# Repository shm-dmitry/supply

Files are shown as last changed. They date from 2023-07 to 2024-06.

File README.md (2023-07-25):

Supply for my purposes

Yes, I know about china and ali.

But it was intresting to create it manually.

Input: AC 180..240V

Outputs:
1. DC 0..50V up to 10A (banana jack). Support CV and CC modes.
2. DC 5V up to 15A (banana jack & 2.54 pin pannel)
3. DC 3.3V up to 1A
4. one PWM channel 5V & 3.3V up to 1A each (configured from UI)
5. one USB port with QC2.0 chip (up to 18W)
6. two USB ports with 5V/1.5A output
7. One Li-Ion charger with 1A output current

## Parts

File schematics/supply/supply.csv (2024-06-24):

Source: | /opt/work-iot/supply/schematics/supply/supply.kicad_sch
Date: | Вт 26 дек 2023 18:33:18
Tool: | Eeschema 7.0.9-7.0.9~ubuntu22.04.1
Generator: | /usr/share/kicad/plugins/bom_csv_grouped_by_value_with_fp.py
Component Count: | 283
Ref | Qnty | Value | Cmp name | Footprint | Description | Vendor | DNP
C1, C7, C20, C27, C39, C50, C52 | 7 | 100 nF | C | Capacitor_SMD:C_0603_1608Metric | Unpolarized capacitor
C2, C17, C19, C22, C23, C25 | 6 | 22 uF | C | Capacitor_SMD:C_1210_3225Metric | Unpolarized capacitor
C3, C6, C64, C65, C66, C67 | 6 | 10 uF | C | Capacitor_SMD:C_0603_1608Metric | Unpolarized capacitor
C4, C42, C61, C62 | 4 | 10 nF | C | Capacitor_SMD:C_0603_1608Metric | Unpolarized capacitor
C5, C51 | 2 | 2 nF | C | Capacitor_SMD:C_0603_1608Metric | Unpolarized capacitor
C8, C10, C11, C26, C38, C45, C48, C49, C53, C54, C63 | 11 | 1 uF | C | Capacitor_SMD:C_0603_1608Metric | Unpolarized capacitor
C9 | 1 | 220 uF@35V | C_Polarized | Capacitor_THT:CP_Radial_D8.0mm_P3.50mm | Polarized capacitor
C12, C13 | 2 | К73-17 0.15 uF@400V | C | Capacitor_THT:C_Rect_L16.5mm_W7.3mm_P15.00mm_MKT | Unpolarized capacitor
C14, C15 | 2 | К73-17 0.022 uF@630V | C | Capacitor_THT:C_Rect_L13.0mm_W6.0mm_P10.00mm_FKS3_FKP3_MKS4 | Unpolarized capacitor
C16, C21, C24 | 3 | 1000 uF@16V | C_Polarized | Capacitor_THT:CP_Radial_D10.0mm_P5.00mm | Polarized capacitor
C18 | 1 | 2200 uF@35V | C_Polarized | Capacitor_THT:CP_Radial_D16.0mm_P7.50mm | Polarized capacitor
C28, C29, C30, C31, C34, C35, C36, C37, C43, C44, C46, C47 | 12 | 220 nF | C | Capacitor_SMD:C_0603_1608Metric | Unpolarized capacitor
C32, C33 | 2 | 15 pF | C | Capacitor_SMD:C_0603_1608Metric | Unpolarized capacitor
C40, C41, C68 | 3 | 0.1 uF | C | Capacitor_SMD:C_0603_1608Metric | Unpolarized capacitor
C55, C57 | 2 | К73-17 1 uF@400V | C | Capacitor_THT:C_Rect_L24.0mm_W12.8mm_P22.50mm_MKT | Unpolarized capacitor
C56, C58 | 2 | К73-17 0.33 uF@630V | C | Capacitor_THT:C_Rect_L24.0mm_W12.2mm_P22.50mm_MKT | Unpolarized capacitor
C59, C60 | 2 | 2200 uF@63V | C_Polarized | Capacitor_THT:CP_Radial_D18.0mm_P7.50mm | Polarized capacitor
C69 | 1 | 22 pF | C | Capacitor_SMD:C_0603_1608Metric | Unpolarized capacitor
CLR1, CLR4 | 2 | HS 216-30@30х51х25.5mm | COOLER | Library:HS 216-30
CLR2, CLR3 | 2 | HS 239-20 | COOLER | Library:HS-239-20
D1 | 1 | SR540 | D | Diode_THT:D_DO-201AD_P3.81mm_Vertical_AnodeUp | Diode
D2, D6, D9 | 3 | red/green, common cathode, F3 | LED_Dual_AKA | LED_THT:LED_D5.0mm-3 | Dual LED, common cathode on pin 2
D3, D21 | 2 | STTH1R06A | D | Diode_SMD:D_SMA | Diode
D4 | 1 | SMAJ26A | SMAJ26A | Diode_SMD:D_SMA | 400W unidirectional Transient Voltage Suppressor, 26.0Vr, SMA(DO-214AC)
D5, D7, D23, D24, D25, D26 | 6 | SMAJ5.0CA-TR | ESD9B3.3ST5G | Diode_SMD:D_SMA | ESD protection diode, 3.3Vrwm, SOD-923
D8, D22 | 2 | STTH3003CW | D_Dual_CommonCathode_AKA | Package_TO_SOT_THT:TO-247-3_Vertical | Dual diode, common cathode on pin 2
D10, D11 | 2 | SMCJ5.0A | Z3SMCxxx | Diode_SMD:D_SMC | 3000mW Zener Diode, SMC(DO-214AB)
D12 | 1 | L-2060YD | LED | LED_THT:LED_D1.8mm_W3.3mm_H2.4mm | Light emitting diode
D13 | 1 | GNL-3012ED | LED | Connector_JST:JST_XH_B2B-XH-A_1x02_P2.50mm_Vertical | Light emitting diode
D14 | 1 | GNL-3012GD | LED | Connector_JST:JST_XH_B2B-XH-A_1x02_P2.50mm_Vertical | Light emitting diode
D15, D16, D17, D18, D19, D20 | 6 | BAV21WS | D | Diode_SMD:D_SOD-323F | Diode
D27 | 1 | yellow | LED |  | Light emitting diode |  | DNP
D28 | 1 | green | LED |  | Light emitting diode |  | DNP
F1 | 1 | 5A | Fuse | Connector_Wire:SolderWire-0.75sqmm_1x02_P4.8mm_D1.25mm_OD2.3mm | Fuse
F2, F3, F5, F6 | 4 | 3A | Fuse | Connector_Wire:SolderWire-0.75sqmm_1x02_P4.8mm_D1.25mm_OD2.3mm | Fuse
F4 | 1 | 1808, 2A | Fuse | Library:FuseHolder1808 | Fuse
F7, F8 | 2 | 15A | Fuse |  | Fuse |  | DNP
J1 | 1 | Conn_01x02_Pin | Conn_01x02_Pin | Connector_Wire:SolderWire-1.5sqmm_1x02_P6mm_D1.7mm_OD3mm | Generic connector, single row, 01x02, script generated
J2, J3, J5, J6 | 4 | RFShield_OnePiece | RFShield_OnePiece | Library:EMI_SHIELD_1P_2H | One-piece EMI RF shielding cabinet
J4 | 1 | Conn_01x01_Pin | Conn_01x01_Pin | Connector_Wire:SolderWire-1.5sqmm_1x01_D1.7mm_OD3.9mm | Generic connector, single row, 01x01, script generated
J7, J8, J9 | 3 | USB_A | USB_A | Library:USB_A | USB Type A connector
J10, J11, J12, J13 | 4 | Conn_01x04_Pin | Conn_01x04_Pin | Connector_JST:JST_XH_B4B-XH-A_1x04_P2.50mm_Vertical | Generic connector, single row, 01x04, script generated
J14, J15 | 2 | USBASP | Conn_02x05_Odd_Even | Library:DC3-2x05_p2.54 | Generic connector, double row, 02x05, odd/even pin numbering scheme (row 1 odd numbers, row 2 even numbers), script generated (kicad-library-utils/schlib/autogen/connector/)
J16 | 1 | JST XH B3B | Conn_01x03_Socket | Connector_JST:JST_XH_B3B-XH-A_1x03_P2.50mm_Vertical | Generic connector, single row, 01x03, script generated
J17 | 1 | Conn_01x06_Pin | Conn_01x06_Pin | Connector_JST:JST_XH_B6B-XH-A_1x06_P2.50mm_Vertical | Generic connector, single row, 01x06, script generated
J18 | 1 | Conn_01x03_Pin | Conn_01x03_Pin |  | Generic connector, single row, 01x03, script generated
J20 | 1 | Conn_01x05_Pin | Conn_01x05_Pin | Connector_JST:JST_XH_B5B-XH-A_1x05_P2.50mm_Vertical | Generic connector, single row, 01x05, script generated
J21, J22 | 2 | banana jack + fuse 15A | Conn_01x02_Socket | Connector_Wire:SolderWire-1.5sqmm_1x02_P6mm_D1.7mm_OD3mm | Generic connector, single row, 01x02, script generated
J24 | 1 | Conn_01x02_Pin | Conn_01x02_Pin | Connector_JST:JST_XH_B2B-XH-A_1x02_P2.50mm_Vertical | Generic connector, single row, 01x02, script generated |  | DNP
J26 | 1 | Conn_02x04_Odd_Even | Conn_02x04_Odd_Even | Connector_PinSocket_2.54mm:PinSocket_2x04_P2.54mm_Horizontal | Generic connector, double row, 02x04, odd/even pin numbering scheme (row 1 odd numbers, row 2 even numbers), script generated (kicad-library-utils/schlib/autogen/connector/)
J27, J28 | 2 | jst xh angle | Conn_01x02_Socket | Connector_JST:JST_XH_S2B-XH-A_1x02_P2.50mm_Horizontal | Generic connector, single row, 01x02, script generated
L1 | 1 | AMPLF1260, 4.7 uH | L | Inductor_SMD:L_TaiTech_TMPC1265_13.5x12.5mm | Inductor
L2 | 1 | HPI1040-1R0 | L | Library:Ferrocore-HPI1040 | Inductor
L3 | 1 | 22 uH@0650 | L | Inductor_SMD:L_Chilisin_BMRB00060650 | Inductor
L4 | 1 | SPM6550T-R68M | L | Inductor_SMD:L_Sumida_CDMC6D28_7.25x6.5mm | Inductor
M1 | 1 | Fan | Fan | Connector_JST:JST_XH_B2B-XH-A_1x02_P2.50mm_Vertical | Fan
Q1, Q2, Q10, Q11 | 4 | STP13NK60Z | Q_NMOS_GDS | Package_TO_SOT_THT:TO-220-3_Vertical | N-MOSFET transistor, gate/drain/source
Q3, Q4, Q6, Q7, Q8, Q9, Q12 | 7 | IRLML0030 | IRLML0030 | Package_TO_SOT_SMD:SOT-23 | 5.3A Id, 30V Vds, 27mOhm Rds, N-Channel HEXFET Power MOSFET, SOT-23
Q5 | 1 | IRLML5203 | IRLML5203 | Package_TO_SOT_SMD:SOT-23 | -3.0A Id, -30V Vds, 98mOhm Rds, P-Channel HEXFET Power MOSFET, SOT-23
Q13, Q14 | 2 | IRF7425PbF | IRF7404 | Package_SO:SOIC-8_3.9x4.9mm_P1.27mm | -6.7A Id, -20V Vds, P-Channel HEXFET Power MOSFET, SO-8
R1, R53, R54 | 3 | 220 | R | Resistor_SMD:R_0805_2012Metric | Resistor
R2, R3, R4, R5, R20, R23, R24, R25, R26, R27, R29, R30, R31, R35, R37, R40, R41, R42, R44, R45, R46, R47, R48, R49, R55, R56, R57, R70 | 28 | 10K | R | Resistor_SMD:R_0805_2012Metric | Resistor
R6, R50 | 2 | 5K | R | Resistor_SMD:R_0805_2012Metric | Resistor
R7, R52 | 2 | 22 | R | Resistor_SMD:R_0805_2012Metric | Resistor
R8 | 1 | 100K | R | Resistor_SMD:R_0805_2012Metric | Resistor
R9 | 1 | 33K | R | Resistor_SMD:R_0805_2012Metric | Resistor
R10 | 1 | 2K | R | Resistor_SMD:R_0805_2012Metric | Resistor
R11, R13, R17, R64, R65 | 5 | 0.01 | R | Resistor_SMD:R_1206_3216Metric | Resistor
R12, R16, R22, R28, R69 | 5 | 510 | R | Resistor_SMD:R_0805_2012Metric | Resistor
R14, R18 | 2 | 0 | R | Resistor_SMD:R_0805_2012Metric | Resistor
R15, R58 | 2 | 100@2W | R | Resistor_THT:R_Axial_DIN0617_L17.0mm_D6.0mm_P5.08mm_Vertical | Resistor
R19 | 1 | 100 | R | Resistor_SMD:R_0805_2012Metric | Resistor
R21 | 1 | 3K3 | R | Resistor_SMD:R_0805_2012Metric | Resistor
R32, R34 | 2 | 4K7 | R | Resistor_SMD:R_0805_2012Metric | Resistor
R33, R36 | 2 | 270 | R | Resistor_SMD:R_0805_2012Metric | Resistor
R38, R39 | 2 | 5K1 | R | Resistor_SMD:R_0805_2012Metric | Resistor
R43, R51, R60, R63, R66, R67, R68 | 7 | 1K | R | Resistor_SMD:R_0805_2012Metric | Resistor
R59 | 1 | 9K1 | R | Resistor_SMD:R_0805_2012Metric | Resistor
R61 | 1 | 0.01 | R | Resistor_SMD:R_2512_6332Metric | Resistor
R62 | 1 | 47K | R | Resistor_SMD:R_0805_2012Metric | Resistor
RV1, RV2 | 2 | CT1206M6G | Varistor | Resistor_SMD:R_1206_3216Metric | Voltage dependent resistor
RV3, RV4 | 2 | RM065, 10K | R_Potentiometer | Potentiometer_THT:Potentiometer_Runtron_RM-065_Vertical | Potentiometer
SW1, SW2 | 2 | EC11W**** | RotaryEncoder_Switch | Rotary_Encoder:RotaryEncoder_Alps_EC11E-Switch_Vertical_H20mm_CircularMountingHoles | Rotary encoder, dual channel, incremental quadrate outputs, with switch
SW3 | 1 | SW_Push | SW_Push | Connector_JST:JST_XH_B2B-XH-A_1x02_P2.50mm_Vertical | Push button switch, generic, two pins
TH1, TH2 | 2 | MF52-502 5K | Thermistor_NTC | Connector_JST:JST_XH_B2B-XH-A_1x02_P2.50mm_Vertical | Temperature dependent resistor, negative temperature coefficient
TP1 | 1 | 5V_A | TestPoint | TestPoint:TestPoint_Pad_1.0x1.0mm | test point
TP2 | 1 | 5V_B | TestPoint | TestPoint:TestPoint_Pad_1.0x1.0mm | test point
TP3 | 1 | GND | TestPoint | TestPoint:TestPoint_Loop_D2.60mm_Drill1.6mm_Beaded | test point
TP4 | 1 | PW_CS | TestPoint | TestPoint:TestPoint_Pad_1.0x1.0mm | test point
TP5 | 1 | PW_VS | TestPoint | TestPoint:TestPoint_Pad_1.0x1.0mm | test point
TP6 | 1 | PW_SHDN# | TestPoint | TestPoint:TestPoint_Pad_1.0x1.0mm | test point
TP7 | 1 | SGN_DAC | TestPoint | TestPoint:TestPoint_Pad_1.0x1.0mm | test point
TP8 | 1 | SGN_GEN | TestPoint | TestPoint:TestPoint_Pad_1.0x1.0mm | test point
TP9 | 1 | F_IC | TestPoint | TestPoint:TestPoint_Pad_1.0x1.0mm | test point
TP10 | 1 | F_R1 | TestPoint | TestPoint:TestPoint_Pad_1.0x1.0mm | test point
TP11 | 1 | F_R2 | TestPoint | TestPoint:TestPoint_Pad_1.0x1.0mm | test point
TP12 | 1 | F_EN | TestPoint | TestPoint:TestPoint_Pad_1.0x1.0mm | test point
TP13 | 1 | BTN_FB | TestPoint | TestPoint:TestPoint_Pad_1.0x1.0mm | test point
TP14 | 1 | IC_FB | TestPoint | TestPoint:TestPoint_Pad_1.0x1.0mm | test point
TP15 | 1 | SGN | TestPoint | TestPoint:TestPoint_Pad_1.0x1.0mm | test point
TP16 | 1 | PW_FB | TestPoint | TestPoint:TestPoint_Pad_1.0x1.0mm | test point
TP17 | 1 | PW_A | TestPoint | TestPoint:TestPoint_Pad_1.0x1.0mm | test point
TP18 | 1 | PW_B | TestPoint | TestPoint:TestPoint_Pad_1.0x1.0mm | test point
TR1 | 1 | ETD 29/16/10@N87 N51@0.5mm / 3+3@1mm*4 | TR_1_1.5x4-7+7 | Library:ETD29_7x7_vertical
TR2 | 1 | ETD 49/25/16@N87 N18@1mm*2/7+7@1mm*4 | TR_1x2_1.5x4_10+10 | Library:ETD49_10x10_horizontal
U1, U29 | 2 | INA3221 | INA3221 | Package_DFN_QFN:Texas_RGV_S-PVQFN-N16_EP2.1x2.1mm | Triple-Channel High-Side Shunt and Bus Voltage Monitor with I2C and SMBUS Compatible Interface, QFN-16
U2 | 1 | XL6009 | XL6009 | Package_TO_SOT_SMD:TO-263-5_TabPin3
U3, U22, U23 | 3 | EL817 | EL817 | Package_DIP:DIP-4_W7.62mm | DC Optocoupler, Vce 35V, DIP-4
U4 | 1 | L78L33ACUTR | L78L33_SOT89 | Package_TO_SOT_SMD:SOT-89-3 | Positive 100mA 30V Linear Regulator, Fixed Output 3.3V, SOT-89
U5, U24 | 2 | UC3525 | UC3525 | Package_SO:SOIC-16W_7.5x10.3mm_P1.27mm | Regulating Pulse Width Modulators, NOR Logic, PDIP-16/SOIC-16
U6, U10, U11 | 3 | LM158DR | LM2904 | Package_SO:SOP-8_3.76x4.96mm_P1.27mm | Dual Operational Amplifiers, DIP-8/SOIC-8/TSSOP-8/VSSOP-8
U7 | 1 | IP2163 | IP2163 | Package_SO:SOP-8_3.9x4.9mm_P1.27mm
U8, U9, U25, U26 | 4 | IR2117 | IR2117 | Package_SO:SOIC-8_3.9x4.9mm_P1.27mm
U12 | 1 | TL432DBZ | TL432DBZ | Package_TO_SOT_SMD:SOT-23-3 | Shunt Regulator, SOT-23
U13 | 1 | LM1085-3.3 | LM1085-3.3 | Package_TO_SOT_SMD:TO-263-3_TabPin2 | 3A 27V Linear Regulator, Fixed Output 3.3V, TO-220/TO-263
U14 | 1 | ATmega328-A | ATmega328-A | Package_QFP:TQFP-32_7x7mm_P0.8mm | 20MHz, 32kB Flash, 2kB SRAM, 1kB EEPROM, TQFP-32
U15 | 1 | ATtiny1616-M | ATtiny1616-M | Package_DFN_QFN:VQFN-20-1EP_3x3mm_P0.4mm_EP1.7x1.7mm | 20MHz, 16kB Flash, 2kB SRAM, 256B EEPROM, VQFN-20
U16 | 1 | Display_1.18inch_st7535 | Display_1.18inch_st7535
U17 | 1 | AD9833xRM | AD9833xRM | Package_SO:MSOP-10_3x3mm_P0.5mm | 10 bit 25 MHz Programmable Waveform Generator, 2.3V to 5.5V, 12.65mW, MSOP-10
U18 | 1 | MCP4726A0T-E/CH | MCP4726 | Package_TO_SOT_SMD:SOT-23-6
U19 | 1 | MAX961 | MAX961 | Package_SO:SSOP-8_2.95x2.8mm_P0.65mm
U20 | 1 | LM158DR | LM2904 | Package_SO:SOP-8_5.28x5.23mm_P1.27mm | Dual Operational Amplifiers, DIP-8/SOIC-8/TSSOP-8/VSSOP-8
U21 | 1 | FAN3100 | FAN3100 | Package_TO_SOT_SMD:SOT-23-5
U27 | 1 | INA169 | INA169 | Package_TO_SOT_SMD:SOT-23-5 | High-Side Measurement Current Shunt Monitor, 60V, SOT-23-5
U28 | 1 | TP4056 | TP4056 | Library:SOP127P600X175-9N
X1 | 1 | HC-49U, 16MHz | Crystal | Crystal:Crystal_HC49-U_Vertical | Two pin crystal
X2 | 1 | 25 MHz | SG-5032CCN | Oscillator:Oscillator_SMD_Fordahl_DFAS15-4Pin_5.0x3.2mm_HandSoldering | CMOS Clock Oscillator 2.5 to 50 MHz

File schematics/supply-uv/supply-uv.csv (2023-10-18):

Source: | /opt/work-iot/supply/schematics/supply-uv/supply-uv.kicad_sch
Date: | Ср 27 сен 2023 10:07:45
Tool: | Eeschema 7.0.7-7.0.7~ubuntu22.04.1
Generator: | /usr/share/kicad/plugins/bom_csv_grouped_by_value_with_fp.py
Component Count: | 81
Ref | Qnty | Value | Cmp name | Footprint | Description | Vendor | DNP
C1 | 1 | 100 uF@350V | C_Polarized | Capacitor_THT:CP_Radial_D18.0mm_P7.50mm | Polarized capacitor
C2 | 1 | 1 uF | C | Capacitor_SMD:C_0603_1608Metric | Unpolarized capacitor
C3 | 1 | 47 uF@450V | C_Polarized | Capacitor_THT:CP_Radial_D16.0mm_P7.50mm | Polarized capacitor
C4 | 1 | 22 uF@50V | C_Polarized | Capacitor_THT:CP_Radial_D5.0mm_P2.00mm | Polarized capacitor
C5, C7, C9 | 3 | 10 nF | C | Capacitor_SMD:C_0603_1608Metric | Unpolarized capacitor
C6 | 1 | JYC3D101KBY | C | Capacitor_THT:C_Disc_D7.0mm_W2.5mm_P5.00mm | Unpolarized capacitor
C8, C10 | 2 | 220 uF@35V | C_Polarized | Capacitor_THT:CP_Radial_D8.0mm_P3.50mm | Polarized capacitor
C11 | 1 | 100 nF | C | Capacitor_SMD:C_0603_1608Metric | Unpolarized capacitor
CLR1 | 1 | HS 184-30@30х41х30mm | COOLER | Library:HS-184-30
CLR2 | 1 | HS 216-30@30х51х25.5mm | COOLER | Library:HS 216-30
CP1, CP3 | 2 | 100 nF | C | Capacitor_SMD:C_0603_1608Metric | Unpolarized capacitor
CP2, CP4 | 2 | 1 uF | C | Capacitor_SMD:C_0603_1608Metric | Unpolarized capacitor
CP5 | 1 | 3300 uF@450V | C_Polarized | Connector_Wire:SolderWire-1.5sqmm_1x02_P6mm_D1.7mm_OD3mm | Polarized capacitor
D1 | 1 | KBU1010 | KBU8M | Diode_THT:Diode_Bridge_Vishay_KBU | Single-Phase Bridge Rectifier, 700V Vrms, 8.0A If, KBU package
D2, D3 | 2 | FR107 | D | Diode_THT:D_DO-41_SOD81_P7.62mm_Horizontal | Diode
D4 | 1 | FR303 | D | Diode_THT:D_DO-201AD_P3.81mm_Vertical_AnodeUp | Diode
D5, D6 | 2 | L-2060YD | LED | LED_THT:LED_D1.8mm_W3.3mm_H2.4mm | Light emitting diode
DP1 | 1 | STTH8S06D | D | Package_TO_SOT_THT:TO-220-2_Vertical | Diode
F1 | 1 | C10G4 with fuseholder | Fuse | Connector_Wire:SolderWire-1.5sqmm_1x02_P6mm_D1.7mm_OD3mm | Fuse
J1 | 1 | Conn_01x02_Pin | Conn_01x02_Pin | Connector_Wire:SolderWire-1.5sqmm_1x02_P6mm_D1.7mm_OD3mm | Generic connector, single row, 01x02, script generated
J2 | 1 | Conn_01x01_Pin | Conn_01x01_Pin | Connector_Wire:SolderWire-1.5sqmm_1x01_D1.7mm_OD3.9mm | Generic connector, single row, 01x01, script generated
J3 | 1 | CW2B-10A-T | Conn_01x03_Pin | Connector_Wire:SolderWire-1.5sqmm_1x03_P7.8mm_D1.7mm_OD3.9mm | Generic connector, single row, 01x03, script generated
JP1 | 1 | PFC_VCC_OK# | Jumper_2_Open | TestPoint:TestPoint_2Pads_Pitch2.54mm_Drill0.8mm | Jumper, 2-pole, open
JP2 | 1 | PFC Enable | SolderJumper_2_Open | Jumper:SolderJumper-2_P1.3mm_Open_TrianglePad1.0x1.5mm | Solder Jumper, 2-pole, open
K1 | 1 | SRD-12VDC-SL-C | SANYOU_SRD_Form_C | Relay_THT:Relay_SPDT_SANYOU_SRD_Series_Form_C | Sanyo SRD relay, Single Pole Miniature Power Relay,
L1 | 1 | BLM18EG221SN1D | L | Inductor_SMD:L_0603_1608Metric | Inductor
Q1 | 1 | IRLML5203 | IRLML5203 | Package_TO_SOT_SMD:SOT-23 | -3.0A Id, -30V Vds, 98mOhm Rds, P-Channel HEXFET Power MOSFET, SOT-23
QP1, QP2 | 2 | STP13NK60Z | Q_NMOS_GDS | Package_TO_SOT_THT:TO-220-3_Vertical | N-MOSFET transistor, gate/drain/source
R1, R2, R3 | 3 | JNR13S500L | R_Trim | Resistor_THT:R_Axial_DIN0516_L15.5mm_D5.0mm_P7.62mm_Vertical | Trimmable resistor (preset resistor)
R4 | 1 | 50 | R | Resistor_SMD:R_0805_2012Metric | Resistor
R5 | 1 | 62K | R | Resistor_SMD:R_0805_2012Metric | Resistor
R6, R7 | 2 | 1M | R | Resistor_THT:R_Axial_DIN0207_L6.3mm_D2.5mm_P7.62mm_Horizontal | Resistor
R8 | 1 | 305K | R | Resistor_THT:R_Axial_DIN0207_L6.3mm_D2.5mm_P7.62mm_Horizontal | Resistor
R9 | 1 | 33 | R | Resistor_SMD:R_0805_2012Metric | Resistor
R10, R17 | 2 | 10K | R | Resistor_SMD:R_0805_2012Metric | Resistor
R11, R12, R16 | 3 | 1K | R | Resistor_SMD:R_0805_2012Metric | Resistor
R13 | 1 | 1K2 | R | Resistor_SMD:R_0805_2012Metric | Resistor
R14 | 1 | 20K | R | Resistor_SMD:R_0805_2012Metric | Resistor
R15 | 1 | 4K7 | R | Resistor_SMD:R_0805_2012Metric | Resistor
R18 | 1 | 200K | R | Resistor_SMD:R_0805_2012Metric | Resistor
RP1 | 1 | 20K | R | Resistor_SMD:R_0805_2012Metric | Resistor
RP2 | 1 | 0.01 | R | Resistor_SMD:R_2512_6332Metric | Resistor
RP3 | 1 | 10K | R | Resistor_SMD:R_0805_2012Metric | Resistor
RP4 | 1 | 220 | R | Resistor_SMD:R_0805_2012Metric | Resistor
RP5, RP6, RP7, RP9, RP10, RP11, RP13, RP14, RP15 | 9 | 750K | R | Resistor_SMD:R_0805_2012Metric | Resistor
RP8 | 1 | 70K | R | Resistor_SMD:R_0805_2012Metric | Resistor
RP12 | 1 | 17K | R | Resistor_SMD:R_0805_2012Metric | Resistor
RP16 | 1 | 60K | R | Resistor_SMD:R_0805_2012Metric | Resistor
RV1 | 1 | FNR-14K431 | Varistor | Resistor_THT:R_Radial_Power_L16.1mm_W9.0mm_P7.37mm | Voltage dependent resistor
TP1 | 1 | HV GND | TestPoint | TestPoint:TestPoint_THTPad_3.0x3.0mm_Drill1.5mm | test point
TP2 | 1 | 400V | TestPoint | TestPoint:TestPoint_Pad_2.0x2.0mm | test point
TR1 | 1 | ETD 34/17/11@N87@s=5mm N25@1mm*2 | TR_1x2-8+8 | Library:ETD34_7x7_vertical
TR2 | 1 | ETD 29/16/10@N87@s=0.2mm N56/13/9@0.5mm | TR_3x1-7+7 | Library:ETD29_7x7_vertical
U1 | 1 | ICE2PCS01 | ICE2PCS01 | Package_SO:SO-8_3.9x4.9mm_P1.27mm | Standalone PFC Controller in CCM, DIP-8/SOIC-8
U2 | 1 | TL331 | TL331 | Package_TO_SOT_SMD:SOT-23-5 | Single Differential Comparator with Open-Collector Output, SOT-23-5
U3 | 1 | R7731 | R7731 | Package_TO_SOT_SMD:SOT-23-6
U4 | 1 | EL817 | EL817 | Package_DIP:DIP-4_W7.62mm | DC Optocoupler, Vce 35V, DIP-4
U5 | 1 | TL432DBZ | TL432DBZ | Package_TO_SOT_SMD:SOT-23-3 | Shunt Regulator, SOT-23
Y1 | 1 | B32022A3223M000 | C | Capacitor_THT:C_Rect_L18.0mm_W6.0mm_P15.00mm_FKS3_FKP3 | Unpolarized capacitor

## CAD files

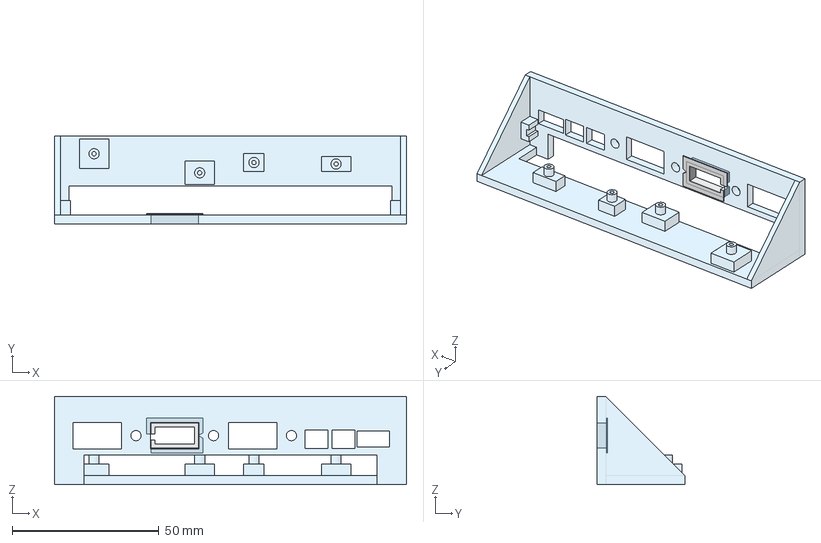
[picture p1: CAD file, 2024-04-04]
3d/box.FCStd
120.0 x 30.0 x 30.0 mm
matrix-front
matrix-usb

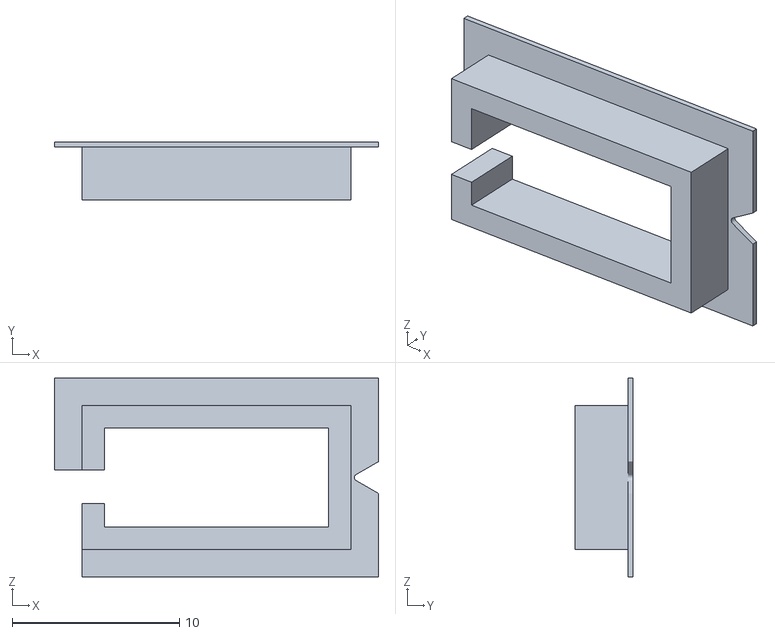
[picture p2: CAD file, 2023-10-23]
3d/box-matrix-usb.stl
19.4 x 3.50 x 11.9

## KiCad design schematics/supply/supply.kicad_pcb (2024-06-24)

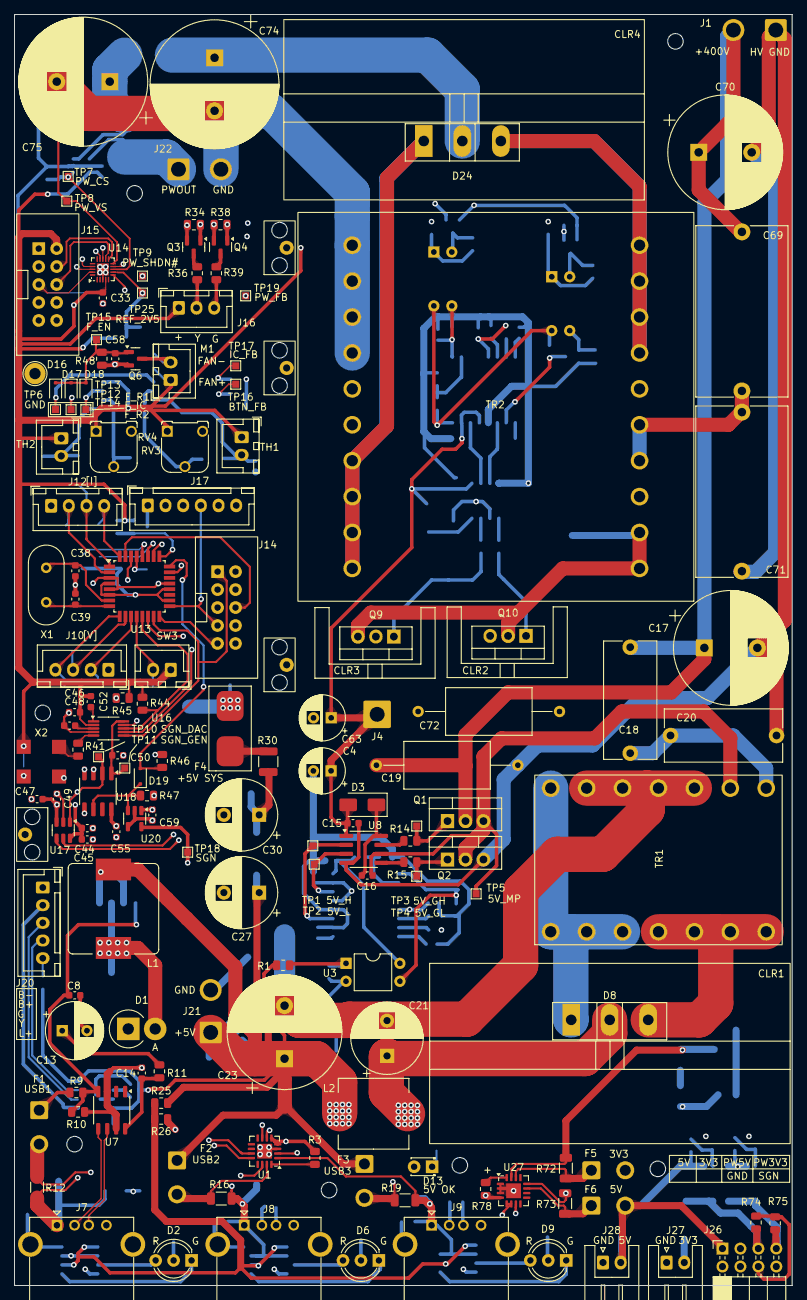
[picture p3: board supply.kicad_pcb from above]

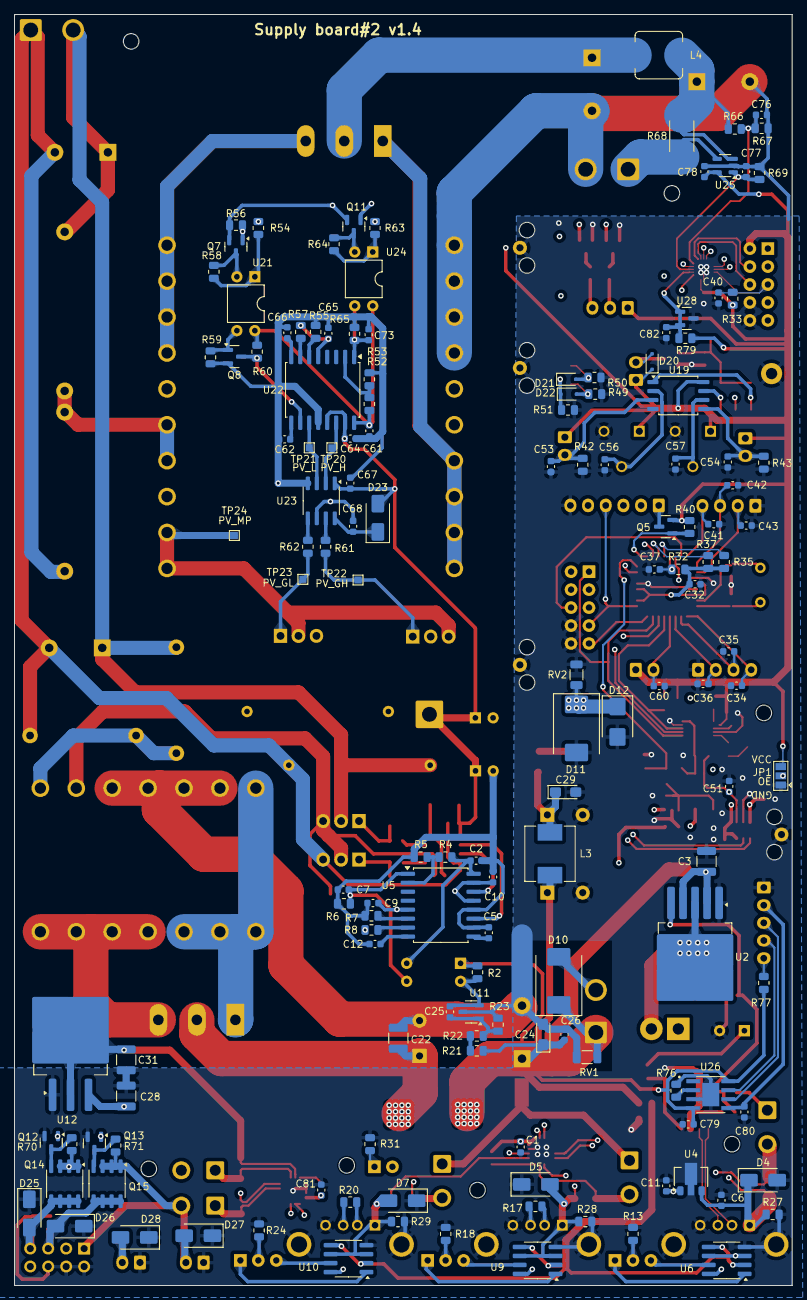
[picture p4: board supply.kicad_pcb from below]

Board: 4 copper layers, 110.0 x 179.8 mm, 311 parts (146 on the bottom side), 162 nets.

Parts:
C1, C2, C7, C12, C15, C25, C33, C48, C61, C66, C67, C73, C81: 100 nF; C_0603_1608Metric
C3, C22, C28, C31: 22 uF; C_1210_3225Metric
C4, C63: 47 uF@35V; CP_Radial_D6.3mm_P2.50mm
C5, C6, C10, C11, C44, C47, C62, C64, C79, C80: 10 uF; C_0603_1608Metric
C8, C34, C35, C41, C42, C52, C76, C77: 10 nF; C_0603_1608Metric
C9, C65: 2.2 nF; C_0603_1608Metric
C13: 220 uF@35V; CP_Radial_D8.0mm_P3.50mm
C14, C16, C26, C32, C46, C55, C58, C59, C60, C68, C78: 1 uF; C_0603_1608Metric
C17, C70: 47 uF@450V; CP_Radial_D16.0mm_P7.50mm
C18, C20: К73-17 0.15 uF@400V; C_Rect_L16.5mm_W7.3mm_P15.00mm_MKT
C19, C72: К73-17 0.22 uF@630V; C_Axial_L12.0mm_D6.5mm_P20.00mm_Horizontal
C21, C27, C30: 1000 uF@16V; CP_Radial_D10.0mm_P5.00mm
C23: 2200 uF@35V; CP_Radial_D16.0mm_P7.50mm
C24, C29: 22 uF; CP_EIA-3216-10_Kemet-I_Pad1.58x1.35mm_HandSolder
C36, C37, C40, C43, C53, C54, C56, C57: 220 nF; C_0603_1608Metric
C38, C39: 15 pF; C_0603_1608Metric
C45, C49, C51: 0.1 uF; C_0603_1608Metric
C50: 22 pF; C_0603_1608Metric
C69, C71: К73-17 1 uF@400V; C_Rect_L24.0mm_W12.8mm_P22.50mm_MKT
C74, C75: 2200 uF@63V; CP_Radial_D18.0mm_P7.50mm
C82: 4.7 uF; C_0603_1608Metric
CLR1, CLR4: HS 216-30@30х51х25.5mm; HS 216-30
CLR2, CLR3: HS 239-20; HS-239-20
D1: SR540; D_DO-201AD_P3.81mm_Vertical_AnodeUp
D2, D6, D9: red/green, common cathode, F3; LED_D5.0mm-3
D3, D23: STTH1R06A; D_SMA
D4: SMAJ26A; D_SMA
D5, D7, D25, D26, D27, D28: SMAJ5.0CA-TR; D_SMA
D8, D24: STTH3003CW; TO-247-3_Vertical
D10, D11: SMCJ5.0A; D_SMC
D12: 1SMB5919B; D_SMB
D13: L-2060YD; LED_D1.8mm_W3.3mm_H2.4mm
D16, D17, D18, D19, D20, D21, D22: BAV21WS; D_SOD-323F
F1: 5A; SolderWire-0.75sqmm_1x02_P4.8mm_D1.25mm_OD2.3mm
F2, F3, F5, F6: 3A; SolderWire-0.75sqmm_1x02_P4.8mm_D1.25mm_OD2.3mm
F4: 1808, 2A; FuseHolder1808
H1, H2, H3, H4, H5, H6, H7: MountingHole; MountingHole_2.2mm_M2
J1: Conn_01x02_Pin; SolderWire-1.5sqmm_1x02_P6mm_D1.7mm_OD3mm
J2, J3, J5, J6: RFShield_OnePiece; EMI_SHIELD_1P_2H
J4: Conn_01x01_Pin; SolderWire-1.5sqmm_1x01_D1.7mm_OD3.9mm
J7, J8, J9: USB_A
J10, J12: Conn_01x04_Pin; JST_XH_B4B-XH-A_1x04_P2.50mm_Vertical
J14, J15: USBASP; DC3-2x05_p2.54
J16: JST XH B3B; JST_XH_B3B-XH-A_1x03_P2.50mm_Vertical
J17: Conn_01x06_Pin; JST_XH_B6B-XH-A_1x06_P2.50mm_Vertical
J20: Conn_01x05_Pin; JST_XH_B5B-XH-A_1x05_P2.50mm_Vertical
J21, J22: banana jack + fuse 15A; SolderWire-1.5sqmm_1x02_P6mm_D1.7mm_OD3mm
J26: Conn_02x04_Odd_Even; PinSocket_2x04_P2.54mm_Horizontal
J27, J28: jst xh angle; JST_XH_S2B-XH-A_1x02_P2.50mm_Horizontal
JP1: SolderJumper_3_Open; SolderJumper-3_P1.3mm_Open_Pad1.0x1.5mm
L1: AMPLF1260, 4.7 uH; L_TaiTech_TMPC1265_13.5x12.5mm
L2: HPI1040-1R0; Ferrocore-HPI1040
L3: 22 uH@0650; L_Chilisin_BMRB00060650
L4: SPM6550T-R68M; L_Sumida_CDMC6D28_7.25x6.5mm
M1: Fan; JST_XH_B2B-XH-A_1x02_P2.50mm_Vertical
NT1, NT2: NetTie_2; NetTie-2_SMD_Pad2.0mm
Q1, Q2, Q9, Q10: STP13NK60Z; TO-220-3_Vertical
Q3, Q4, Q6, Q7, Q8, Q11, Q12, Q13: IRLML0030; SOT-23
Q5: IRLML5203; SOT-23
Q14, Q15: IRF7425PbF; SOIC-8_3.9x4.9mm_P1.27mm
R1, R2, R11, R54, R58, R63, R64: 2K; R_0805_2012Metric
R3, R4, R5, R6, R22, R25, R26, R27, R28, R29, R32, R33, R34, R38, R40, R44, R45, R46, R48, R49, R50, R51, R52, R53, R56, R59, R60, R65, R78: 10K; R_0805_2012Metric
R7, R55: 2K2; R_0805_2012Metric
R8, R57: 22; R_0805_2012Metric
R9: 100K; R_0805_2012Metric
R10: 33K; R_0805_2012Metric
R12, R16, R19, R72, R73: 0.01; R_1206_3216Metric
R13, R18, R24, R31, R77, R79: 510; R_0805_2012Metric
R14, R15, R61, R62: 10; R_0805_2012Metric
R17, R20: 0; R_0805_2012Metric
R21: 150; R_0805_2012Metric
R23: 3K3; R_0805_2012Metric
R30: 0.5; R_1210_3225Metric
R35, R37: 4K7; R_0805_2012Metric
R36, R39: 220; R_0805_2012Metric
R41: 100; R_0805_2012Metric
R42, R43: 5K1; R_0805_2012Metric
R47, R67, R70, R71, R74, R75, R76: 1K; R_0805_2012Metric
R66: 9K1; R_0805_2012Metric
R68: 0.01; R_2512_6332Metric
R69: 47K; R_0805_2012Metric
RV1, RV2: CT1206M6G; R_1206_3216Metric
RV3, RV4: RM065, 10K; Potentiometer_Runtron_RM-065_Vertical
SW3: SW_Push; JST_XH_B2B-XH-A_1x02_P2.50mm_Vertical
TH1, TH2: MF52-502 5K; JST_XH_B2B-XH-A_1x02_P2.50mm_Vertical
TP1: 5V_H; TestPoint_Pad_1.0x1.0mm
TP2: 5V_L; TestPoint_Pad_1.0x1.0mm
TP3: 5V_GH; TestPoint_Pad_1.0x1.0mm
TP4: 5V_GL; TestPoint_Pad_1.0x1.0mm
TP5: 5V_MP; TestPoint_Pad_1.0x1.0mm
TP6: GND; TestPoint_Loop_D2.60mm_Drill1.6mm_Beaded
TP7: PW_CS; TestPoint_Pad_1.0x1.0mm
TP8: PW_VS; TestPoint_Pad_1.0x1.0mm
TP9: PW_SHDN#; TestPoint_Pad_1.0x1.0mm
TP10: SGN_DAC; TestPoint_Pad_1.0x1.0mm
TP11: SGN_GEN; TestPoint_Pad_1.0x1.0mm
TP12: F_IC; TestPoint_Pad_1.0x1.0mm
TP13: F_R1; TestPoint_Pad_1.0x1.0mm
TP14: F_R2; TestPoint_Pad_1.0x1.0mm
TP15: F_EN; TestPoint_Pad_1.0x1.0mm
TP16: BTN_FB; TestPoint_Pad_1.0x1.0mm
TP17: IC_FB; TestPoint_Pad_1.0x1.0mm
TP18: SGN; TestPoint_Pad_1.0x1.0mm
TP19: PW_FB; TestPoint_Pad_1.0x1.0mm
TP20: PV_H; TestPoint_Pad_1.0x1.0mm
TP21: PV_L; TestPoint_Pad_1.0x1.0mm
TP22: PV_GH; TestPoint_Pad_1.0x1.0mm
TP23: PV_GL; TestPoint_Pad_1.0x1.0mm
TP24: PV_MP; TestPoint_Pad_1.0x1.0mm
TP25: REF_2V5; TestPoint_Pad_1.0x1.0mm
TR1: ETD 29/16/10@N87 N51@0.5mm / 3+3@1mm*4; ETD29_7x7_vertical
TR2: ETD 49/25/16@N87 N18@1mm*2/7+7@1mm*4; ETD49_10x10_horizontal
U1, U27: INA3221; Texas_RGV0016A_VQFN-16-1EP_4x4mm_P0.65mm_EP2.1x2.1mm
U2: XL6009; TO-263-5_TabPin3
U3, U21, U24: EL817; DIP-4_W7.62mm
U4: L78L33ACUTR; SOT-89-3
U5, U22: UC3525; SOIC-16W_7.5x10.3mm_P1.27mm
U6, U9, U10: LM158DR; SOP-8_3.76x4.96mm_P1.27mm
U7: IP2163; SOP-8_3.9x4.9mm_P1.27mm
U8, U23: IRS21867S; SOIC-8_3.9x4.9mm_P1.27mm
U11: TL432DBZ; SOT-23-3
U12: LM1085-3.3; TO-263-3_TabPin2
U13: ATmega328-A; TQFP-32_7x7mm_P0.8mm
U14: ATtiny1616-M; VQFN-20-1EP_3x3mm_P0.4mm_EP1.7x1.7mm
U16: AD9833xRM; MSOP-10_3x3mm_P0.5mm
U17: MCP4726A0T-E/CH; SOT-23-6
U18: MAX961; SOP-8_3.76x4.96mm_P1.27mm
U19: LM158DR; SOP-8_5.28x5.23mm_P1.27mm
U20: FAN3100; SOT-23-5
U25: INA169; SOT-23-5
U26: TP4056; SOP127P600X175-9N
U28: TL431DBZ; SOT-23
X1: HC-49U, 16MHz; Crystal_HC49-U_Vertical
X2: 25 MHz; Oscillator_SMD_EuroQuartz_XO91-4Pin_7.0x5.0mm

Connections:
/Control & Fan/+5V_VSYS: C1.2, C32.1, C33.1, C44.1, C45.1, C46.1, C47.1, C49.1, C52.2, C55.1, C59.1, C78.2, C81.2, D11.1 (K), D12.1 (K), D20.1 (K), F4.2, J14.2, J15.2, J16.1, JP1.3 (B), M1.1 (+), Q5.2 (S), R3.1, R32.2, R33.2, R35.2, R37.2, R40.2, R44.2, R45.2, R54.2, R63.2, R78.1, R79.2, RV2.1, RV3.1, RV4.1, SW3.1, TH1.1, TH2.1, U1.4 (VS), U1.5 (A0), U6.8 (V+), U9.8 (V+), U10.8 (V+), U13.4 (VCC), U13.6 (VCC), U13.18 (AVCC), U13.20 (AREF), U14.4 (VCC), U16.2 (VDD), U17.3 (VDD), U17.6 (VREF), U18.8 (VCC), U19.8 (V+), U20.1 (VCC), U25.5 (V+), U27.4 (VS), X2.4 (Vcc)
/Control & Fan/ATTINY_RESET#: C40.1, J15.5, R33.1, U14.19 (~RESET/PA0)
/Control & Fan/ATTINY_RXD: J15.4, U14.11 (PB3)
/Control & Fan/ATTINY_TXD: J15.6, U14.12 (PB2)
/Control & Fan/ATTINY_VREF_2V5: C82.1, R79.1, TP25.1, U14.7 (PA6), U28.1 (K), U28.2 (REF)
/Control & Fan/ENABLE_FAN: D17.2 (A), TP12.1, U13.23 (PC0)
/Control & Fan/ENCODER_I_A: C41.1, J12.4, U13.32 (PD2)
/Control & Fan/ENCODER_I_B: C42.1, J12.3, U13.1 (PD3)
/Control & Fan/ENCODER_I_CLICK: C43.1, J12.2, U13.2 (PD4)
/Control & Fan/ENCODER_V_A: C34.1, J10.4, U13.9 (PD5)
/Control & Fan/ENCODER_V_B: C35.1, J10.3, U13.10 (PD6)
/Control & Fan/ENCODER_V_CLICK: C36.1, J10.2, U13.11 (PD7)
/Control & Fan/IS_ONOFF_BUTTON_PRESSED: C60.2, D22.2 (A), R49.2, SW3.2, TP16.1, U13.12 (PB0)
/Control & Fan/MISO: J14.9, U13.16 (PB4)
/Control & Fan/MOSI: J14.1, J17.3, U13.15 (PB3), U16.6 (SDATA)
/Control & Fan/POWER_OUTPUT_CURRENT_SENSE: C77.2, R69.2, TP7.1, U14.8 (PA7), U25.1
/Control & Fan/POWER_OUTPUT_FB: D21.1 (K), D22.1 (K), Q11.1 (G), R51.2, TP19.1
/Control & Fan/POWER_OUTPUT_IC_FB: D21.2 (A), R50.2, TP17.1, U14.6 (PA5)
/Control & Fan/POWER_OUTPUT_OVERLOADED_LED: Q3.1 (G), R34.2, U14.17 (PC2)
/Control & Fan/POWER_OUTPUT_SHUTDOWN#: Q7.1 (G), R56.2, TP9.1, U14.9 (PB5)
/Control & Fan/POWER_OUTPUT_VOLT_SENSE: C76.2, R66.1, R67.2, TP8.1, U14.10 (PB4)
/Control & Fan/POWER_OUTPUT_VOUT_LED: Q4.1 (G), R38.2, U14.18 (PC3)
/Control & Fan/RESET#: C37.1, J14.5, R32.1, U13.29 (~RESET/PC6)
/Control & Fan/SCK: J14.7, J17.4, U13.17 (PB5), U16.7 (SCLK)
/Control & Fan/SCL: R35.1, U1.6 (SCL), U13.28 (PC5), U14.14 (PB0), U17.5 (SCL), U27.5 (A0), U27.6 (SCL)
/Control & Fan/SDA: R37.1, U1.7 (SDA), U13.27 (PC4), U14.13 (PB1), U17.4 (SDA), U27.7 (SDA)
/Control & Fan/SIGNAL_ALWAYS_ON: D19.2 (A), R46.1, U13.24 (PC1)
/Control & Fan/SIGNAL_CS: R44.1, U13.13 (PB1), U16.8 (~FSYNC)
/Control & Fan/SIGNAL_GEN_SHTDN: R45.1, U13.30 (PD0), U18.3 (SHUTDOWN)
/Control & Fan/SIGNAL_OUT: J26.8, Q12.1 (G), Q13.1 (G), TP18.1, U20.5 (OUT)
/Control & Fan/TFT_CS: J17.5, U13.14 (PB2)
/Control & Fan/TFT_DC: J17.2, U13.26 (PC3)
/Control & Fan/TFT_ENABLE#: Q5.1 (G), R40.1, U13.25 (PC2)
/Control & Fan/TXD: J14.6, U13.31 (PD1)
/Internal 5V & out usb/400V: C17.1, C18.2, C19.2, C69.2, C70.1, C72.2, J1.2, Q1.2 (D), Q9.2 (D)
/Internal 5V & out usb/+3.3_VOUT: C31.2, R72.2, U12.2 (VO), U27.15 (IN+2)
/Internal 5V & out usb/+5V_OUT: C23.1, C24.1, C26.2, C27.1, C28.2, C79.2, D10.1 (K), D13.2 (A), J21.1, L2.2, L3.1, NT1.1, NT2.1, R1.2, R21.1, R25.1, R73.2, R77.1, RV1.1, U12.3 (VI), U26.4 (VIN), U26.8 (EN), U27.12 (IN+1)
/Internal 5V & out usb/DCDC_2V5_VREF: R4.2, R5.1, U5.2 (NI)
/Internal 5V & out usb/DCDC_5V_VREF: C2.1, R4.1, U3.4, U5.16 (REF)
/Internal 5V & out usb/DCDC_FEEDBACK: C7.1, R6.1, U3.3, U5.1 (INV)
/Internal 5V & out usb/FEEDBACK: C25.2, R2.2, U3.2, U11.2 (K)
/Internal 5V & out usb/USB_1_+5V: C3.2, L1.2, NT1.2, U2.2 (EN), U2.4 (VIN)
/Internal 5V & out usb/USB_1_BP: C13.1, D1.1 (K), F1.1, R9.1, R11.2
/Internal 5V & out usb/USB_1_D+: J7.3 (D+), U7.6 (DP)
/Internal 5V & out usb/USB_1_D-: J7.2 (D-), U7.5 (DM)
/Internal 5V & out usb/USB_2_3_+5V: F2.1, F3.1, NT2.2
/Internal 5V & out usb/VBUS1_3.3V: C11.2, U4.1 (OUT), U6.3 (+), U6.6 (-)
/Internal 5V & out usb/VBUS_1: C6.2, D4.1 (A1), J7.1 (VBUS), R12.1, R27.1, U1.11 (IN-1), U4.3 (IN)
/Internal 5V & out usb/VBUS_1_+: F1.2, R12.2, U1.12 (IN+1)
/Internal 5V & out usb/VBUS_2: D5.2 (A2), J8.1 (VBUS), R16.1, R28.1, U1.14 (IN-2), U9.3 (+), U9.6 (-)
/Internal 5V & out usb/VBUS_2_+: F2.2, R16.2, U1.15 (IN+2)
/Internal 5V & out usb/VBUS_3: D7.2 (A2), J9.1 (VBUS), R19.1, R29.1, U1.1 (IN-3), U10.3 (+), U10.6 (-)
/Internal 5V & out usb/VBUS_3_+: F3.2, R19.2, U1.2 (IN+3)
/Internal 5V & out usb/VREF_2V5: R25.2, R26.1, U6.2 (-), U6.5 (+), U9.2 (-), U9.5 (+), U10.2 (-), U10.5 (+)
/Internal 5V & out usb/V_STANDBY: C4.1, C10.2, C15.1, C63.1, C64.2, C67.1, D3.2 (A), D23.2 (A), J4.1, U5.13 (VC), U5.15 (VIN), U8.1 (VCC), U22.13 (VC), U22.15 (VIN), U23.1 (VCC)
/Output connectors/3.3V_-: F5.1, R72.1, U27.14 (IN-2)
/Output connectors/3.3V_FUSE: D28.2 (A2), F5.2, J26.3, J27.2, Q14.1 (S), Q14.2 (S), Q14.3 (S), R70.2
/Output connectors/5V_-: F6.1, R73.1, U27.11 (IN-1)
/Output connectors/5V_FUSE: D27.2 (A2), F6.2, J26.1, J28.2, Q15.1 (S), Q15.2 (S), Q15.3 (S), R71.2
/Output connectors/LIION_CHARGE_LED1: J20.4, U26.7 (STAT1)
/Output connectors/LIION_CHARGE_LED2: J20.3, U26.6 (STAT2)
/Output connectors/LIION_CHARGE_VBAT: C80.2, J20.2, U26.5 (VBAT)
/Output connectors/POWER_OUT: J22.1, R68.2, U25.4 (-)
/Output connectors/SIGNAL_OUT_PWR_3V3: D25.2 (A2), J26.7, Q14.5 (D), Q14.6 (D), Q14.7 (D), Q14.8 (D), R74.2
/Output connectors/SIGNAL_OUT_PWR_5V: D26.2 (A2), J26.5, Q15.5 (D), Q15.6 (D), Q15.7 (D), Q15.8 (D), R75.2
/Power output/DCDC_2V5_VREF: R52.2, R53.1, U22.2 (NI)
/Power output/DCDC_5V_VREF: C61.1, R52.1, R60.1, U21.4, U22.16 (REF), U24.4
/Power output/DCDC_FEEDBACK: C73.1, R65.1, U22.1 (INV), U24.3
/Power output/DCDC_SHUTDOWN: Q8.3 (D), R60.2, U22.10 (SD)
GND: C1.1, C3.1, C6.1, C8.1, C11.1, C13.2, C14.1, C21.2, C22.1, C23.2, C24.2, C26.1, C27.2, C28.1, C29.2, C30.2, C31.1, C32.2, C33.2, C34.2, C35.2, C36.2, C37.2, C38.2, C39.2, C40.2, C41.2, C42.2, C43.2, C44.2, C45.2, C46.2, C47.2, C48.1, C49.2, C50.2, C51.2, C53.1, C54.1, C55.2, C56.1, C57.1, C58.1, C59.2, C60.1, C74.2, C75.2, C76.1, C77.1, C78.1, C79.1, C80.1, C81.1, C82.2, D4.2 (A2), D5.1 (A1), D7.1 (A1), D10.2 (A), D11.2 (A), D12.2 (A), D25.1 (A1), D26.1 (A1), D27.1 (A1), D28.1 (A1), J2.1 (Shield), J3.1 (Shield), J5.1 (Shield), J6.1 (Shield), J7.4 (GND), J7.5 (Shield), J8.4 (GND), J8.5 (Shield), J9.4 (GND), J9.5 (Shield), J10.1, J12.1, J14.8, J14.10, J15.8, J15.10, J17.6, J20.1, J21.2, J22.2, J26.2, J26.4, J26.6, J27.1, J28.1, JP1.1 (A), Q3.2 (S), Q4.2 (S), Q6.2 (S), Q7.2 (S), Q11.2 (S), Q12.2 (S), Q13.2 (S), R10.2, R13.2, R18.2, R23.2, R24.2, R26.2, R27.2, R28.2, R29.2, R31.1, R34.1, R38.1, R42.1, R43.1, R46.2, R47.1, R48.1, R49.1, R50.1, R51.1, R56.1, R67.1, R69.1, R74.1, R75.1, R76.1, RV1.2, RV2.2, RV3.3, RV4.3, TP6.1, TR1.4, TR1.6, TR1.8, TR1.10, TR2.14, TR2.16, TR2.18, TR2.20, U1.3 (GND), U1.17 (EP), U2.1 (GND), U4.2 (GND), U6.4 (V-), U7.3 (GND), U7.7 (SEL), U9.4 (V-), U10.4 (V-), U11.3 (A), U12.1 (GND), U13.3 (GND), U13.5 (GND), U13.21 (GND), U14.3 (GND), U14.21 (GND), U16.4 (DGND), U16.9 (AGND), U17.2 (GND), U18.4 (LATCH_EN), U18.5 (GND), U19.4 (V-), U20.2 (GND), U20.4 (IN-), U25.2 (GND), U26.3 (VSS), U26.9 (GND), U27.1 (IN-3), U27.2 (IN+3), U27.3 (GND), U27.17 (EP), U28.3 (A), X2.2 (GND)
GNDPWR: C2.2, C4.2, C5.2, C7.2, C9.2, C10.1, C12.2, C15.2, C17.2, C19.1, C20.1, C61.2, C62.2, C63.2, C64.1, C65.2, C66.2, C67.2, C70.2, C71.1, C72.1, C73.2, J1.1, Q2.3 (S), Q8.2 (S), Q10.3 (S), R5.2, R6.2, R7.2, R53.2, R55.2, R59.2, R65.2, U5.10 (SD), U5.12 (GND), U8.4 (COM), U22.12 (GND), U23.4 (COM)
unnamed: C18.1, C20.2, TR1.14
unnamed: C29.1, C30.1, L3.2, R30.1
unnamed: C69.1, C71.2, TR2.7, TR2.9
unnamed: D1.2 (A), L1.1, U2.3 (SW)
unnamed: D2.1 (A1), U6.1
unnamed: D2.3 (A2), U6.7
unnamed: D2.2 (K), R13.1
unnamed: C16.1, D3.1 (K), U8.8 (VB)
unnamed: D6.1 (A1), U9.1
unnamed: D6.3 (A2), U9.7
unnamed: D6.2 (K), R18.1
unnamed: D8.1 (A), TR1.1, TR1.2, TR1.3, TR1.5
unnamed: D8.3 (A), TR1.7, TR1.9, TR1.11, TR1.13
unnamed: C21.1, C22.2, D8.2 (K), L2.1
unnamed: D9.1 (A1), U10.1
unnamed: D9.3 (A2), U10.7
unnamed: D9.2 (K), R24.1
unnamed: D13.1 (K), R31.2
unnamed: D16.2 (A), TP13.1, U19.1
unnamed: C58.2, D16.1 (K), D17.1 (K), D18.1 (K), Q6.1 (G), R48.2, TP15.1
unnamed: D18.2 (A), TP14.1, U19.7
unnamed: D19.1 (K), R47.2, U18.6 (Q), U20.3 (IN+)
unnamed: D20.2 (A), M1.2 (-), Q6.3 (D)
unnamed: C68.1, D23.1 (K), U23.8 (VB)
unnamed: D24.1 (A), TR2.2, TR2.4, TR2.6, TR2.8
unnamed: D24.3 (A), TR2.13, TR2.15, TR2.17, TR2.19
unnamed: C74.1, D24.2 (K), L4.1
unnamed: F4.1, R30.2
unnamed: J8.3 (D+), R17.2
unnamed: J8.2 (D-), R17.1
unnamed: J9.3 (D+), R20.2
unnamed: J9.2 (D-), R20.1
unnamed: J16.2, R36.2
unnamed: J16.3, R39.2
unnamed: J17.1, Q5.3 (D)
unnamed: J20.5, R77.2
unnamed: JP1.2 (C), X2.1 (OE)
unnamed: Q1.1 (G), R14.2, TP3.1
unnamed: C16.2, Q1.3 (S), Q2.2 (D), TP5.1, TR1.12, U8.6 (VS)
unnamed: Q2.1 (G), R15.2, TP4.1
unnamed: Q3.3 (D), R36.1
unnamed: Q4.3 (D), R39.1
unnamed: Q7.3 (D), R58.1, U21.2
unnamed: Q8.1 (G), R59.1, U21.3
unnamed: Q9.1 (G), R61.2, TP22.1
unnamed: C68.2, Q9.3 (S), Q10.2 (D), TP24.1, TR2.1, TR2.3, U23.6 (VS)
unnamed: Q10.1 (G), R62.2, TP23.1
unnamed: Q11.3 (D), R64.1, U24.2
unnamed: Q12.3 (D), Q14.4 (G), R70.1
unnamed: Q13.3 (D), Q15.4 (G), R71.1
unnamed: R1.1, R2.1, U3.1
unnamed: R21.2, R22.1
unnamed: R54.1, R58.2, U21.1
unnamed: R63.1, R64.2, U24.1
unnamed: R3.2, U1.16 (VPU)
unnamed: C8.2, R9.2, R10.1, U2.5 (FB), U7.4 (FB)
unnamed: C5.1, U5.9 (COMP)
unnamed: C9.1, R8.1, U5.5 (CT)
unnamed: R8.2, U5.7 (DISCH)
unnamed: TP1.1, U5.11 (OUTA), U8.2 (HIN)
unnamed: TP2.1, U5.14 (OUTB), U8.3 (LIN)
unnamed: R7.1, U5.6 (RT)
unnamed: C12.1, U5.8 (SS)
unnamed: C14.2, R11.1, U7.8 (VBUS)
unnamed: R14.1, U8.7 (HO)
unnamed: R15.1, U8.5 (LO)
unnamed: C25.1, R22.2, R23.1, U11.1 (REF)
unnamed: C38.1, U13.7 (XTAL1/PB6), X1.2
unnamed: C39.1, U13.8 (XTAL2/PB7), X1.1
unnamed: C48.2, U16.3 (CAP/2.5V)
unnamed: C52.1, U16.1 (COMP)
unnamed: R41.1, U16.5 (MCLK)
unnamed: C50.1, TP11.1, U16.10 (VOUT), U18.1 (IN+)
unnamed: C51.1, TP10.1, U17.1 (VOUT), U18.2 (IN-)
unnamed: C53.2, R42.2, TH1.2, U19.3 (+)
unnamed: C56.2, RV3.2, U19.2 (-)
unnamed: C54.2, R43.2, TH2.2, U19.5 (+)
unnamed: C57.2, RV4.2, U19.6 (-)
unnamed: C62.1, U22.9 (COMP)
unnamed: C65.1, R57.1, U22.5 (CT)
unnamed: R57.2, U22.7 (DISCH)
unnamed: TP21.1, U22.11 (OUTA), U23.3 (LIN)
unnamed: TP20.1, U22.14 (OUTB), U23.2 (HIN)
unnamed: R55.1, U22.6 (RT)
unnamed: C66.1, U22.8 (SS)
unnamed: R61.1, U23.7 (HO)
unnamed: R62.1, U23.5 (LO)
unnamed: C75.1, L4.2, R66.2, R68.1, U25.3 (+)
unnamed: R76.2, U26.2 (ISET)
unnamed: R78.2, U27.16 (VPU)
unnamed: R41.2, X2.3 (OUT)

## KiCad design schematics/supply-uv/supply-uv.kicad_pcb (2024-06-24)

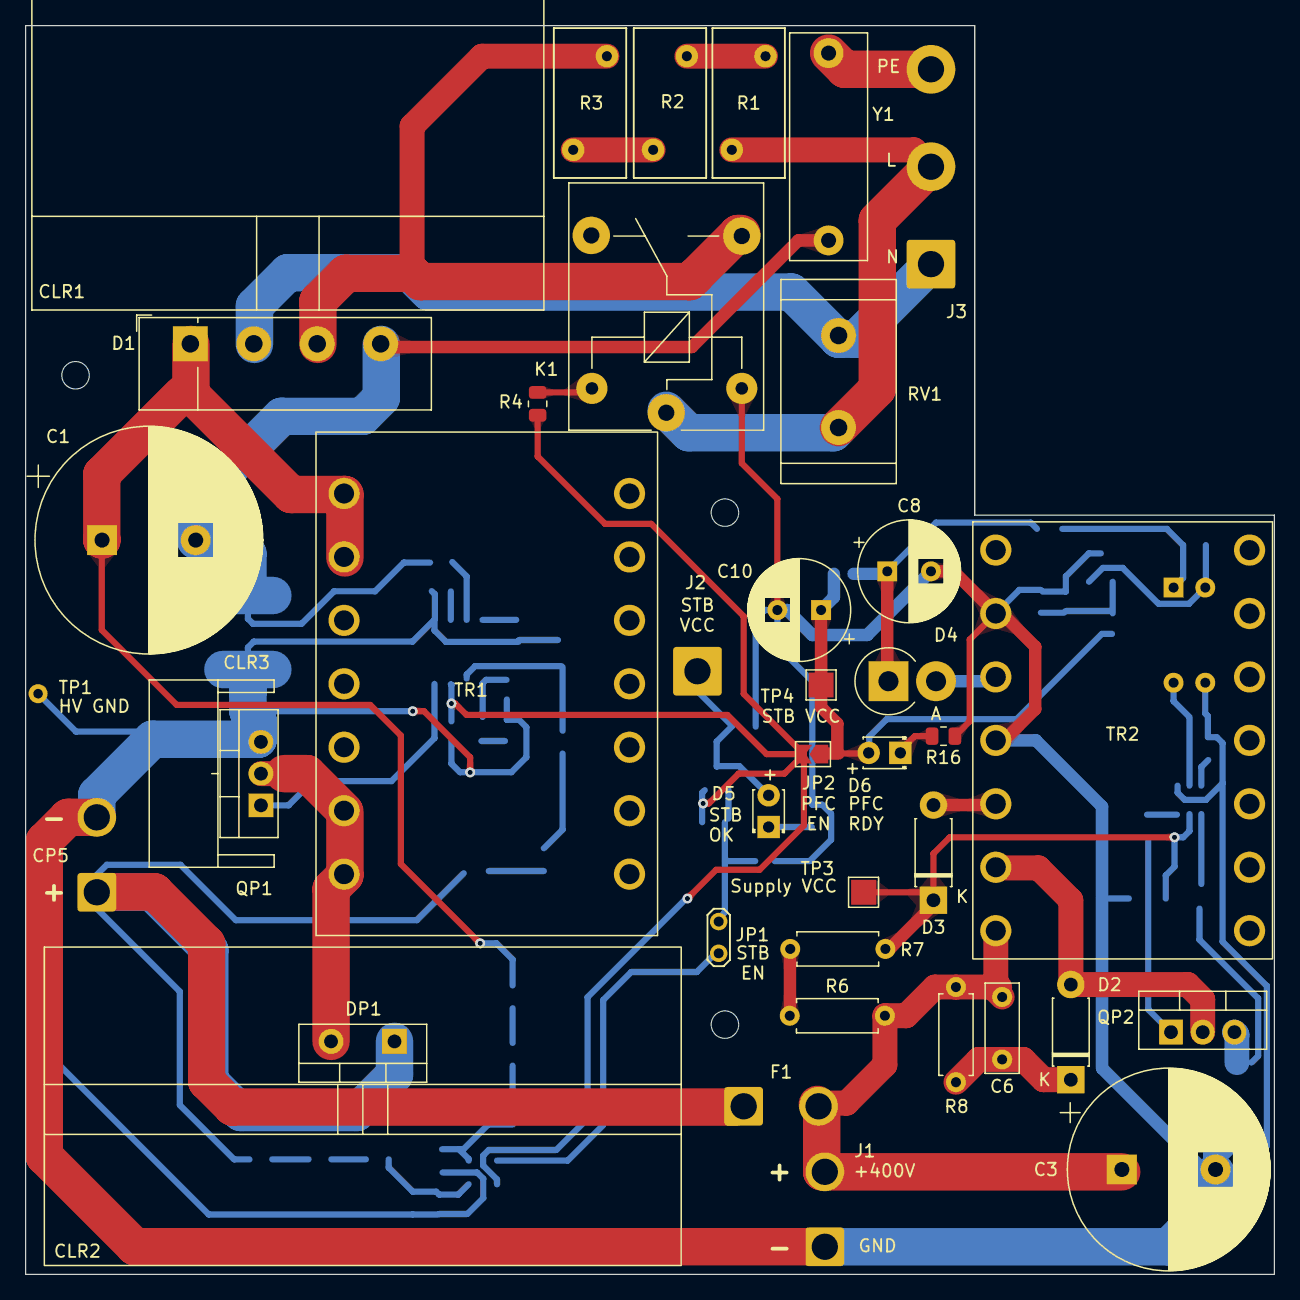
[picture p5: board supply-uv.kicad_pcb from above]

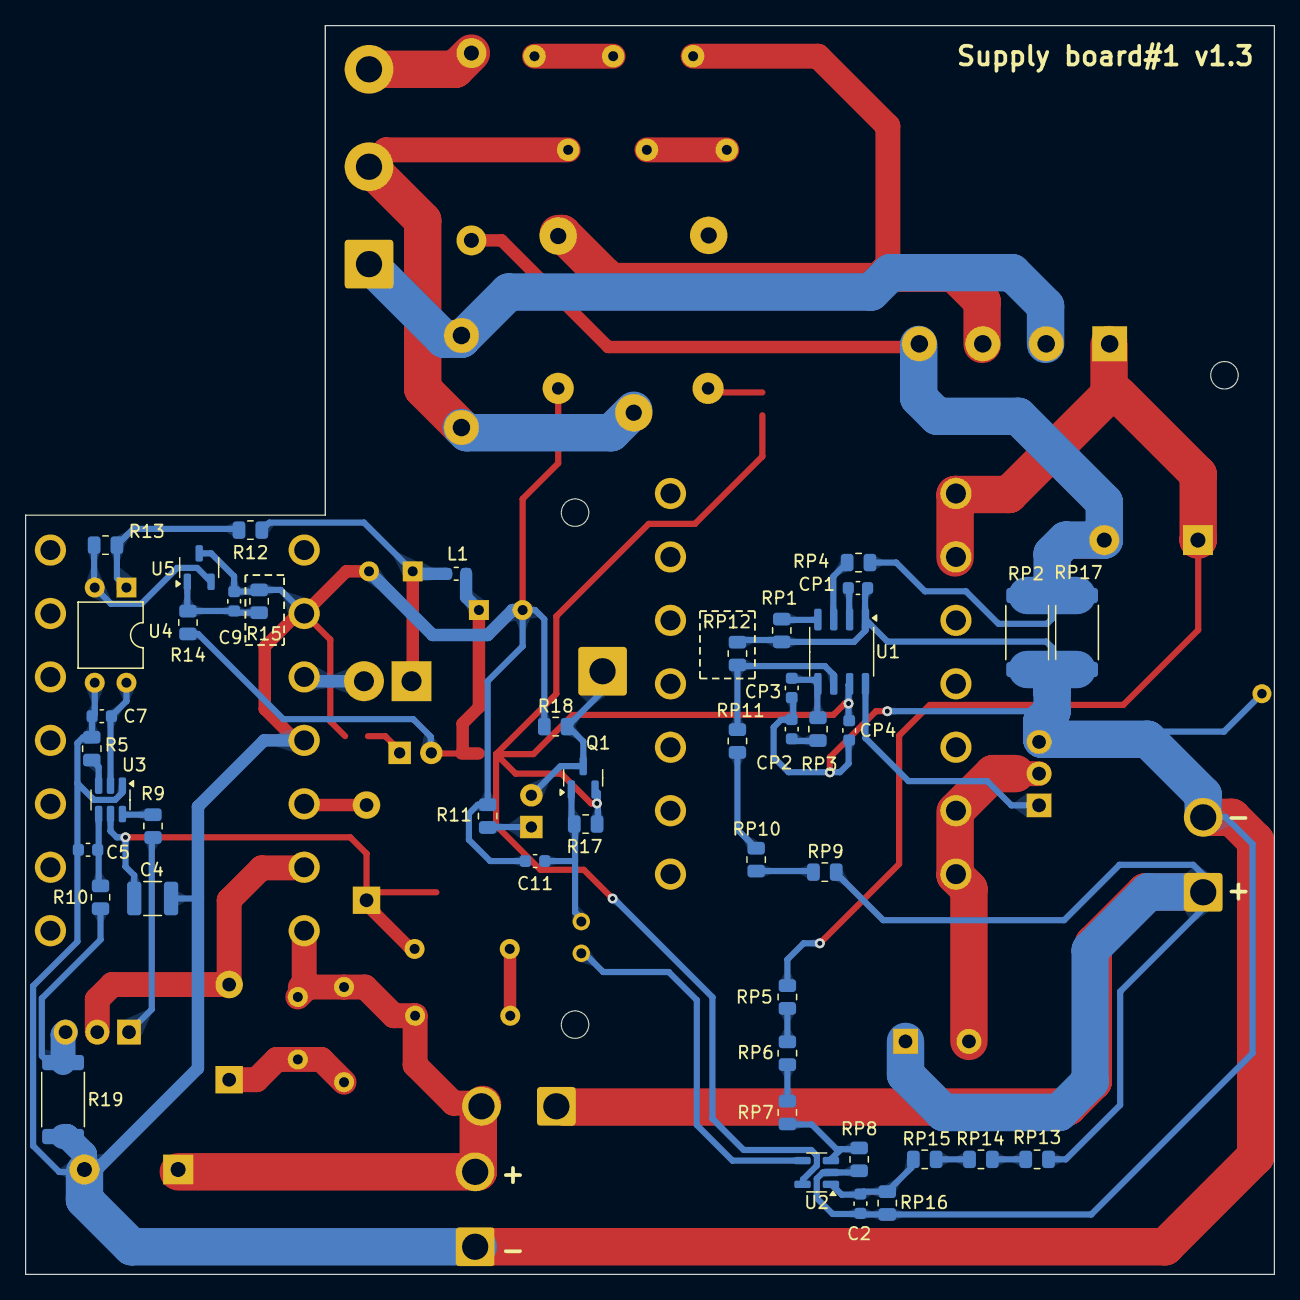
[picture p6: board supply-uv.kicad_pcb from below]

Board: 2 copper layers, 100.0 x 100.0 mm, 88 parts (45 on the bottom side), 51 nets.

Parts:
C1: 100 uF@350V; CP_Radial_D18.0mm_P7.50mm
C2: 1 uF; C_0603_1608Metric
C3: 47 uF@450V; CP_Radial_D16.0mm_P7.50mm
C4: 22 uF; C_1210_3225Metric
C5, C7, C9: 10 nF; C_0603_1608Metric
C6: JYC3D101KBY; C_Disc_D7.0mm_W2.5mm_P5.00mm
C8, C10: 220 uF@35V; CP_Radial_D8.0mm_P3.50mm
C11: 100 nF; C_0603_1608Metric
CLR1: HS 184-30@30х41х30mm; HS-184-30
CLR2: HS 216-30@30х51х25.5mm; HS 216-30
CLR3: HS077@20x15x10mm; HS-077
CP1, CP3: 100 nF; C_0603_1608Metric
CP2, CP4: 1 uF; C_0603_1608Metric
CP5: 3300 uF@450V; SolderWire-1.5sqmm_1x02_P6mm_D1.7mm_OD3mm
D1: KBU1010; Diode_Bridge_Vishay_KBU
D2, D3: FR107; D_DO-41_SOD81_P7.62mm_Horizontal
D4: FR303; D_DO-201AD_P3.81mm_Vertical_AnodeUp
D5, D6: L-2060YD; LED_D1.8mm_W3.3mm_H2.4mm
DP1: STTH8S06D; TO-220-2_Vertical
F1: C10G4 with fuseholder; SolderWire-1.5sqmm_1x02_P6mm_D1.7mm_OD3mm
H1, H2, H3: MountingHole; MountingHole_2.2mm_M2
J1: Conn_01x02_Pin; SolderWire-1.5sqmm_1x02_P6mm_D1.7mm_OD3mm
J2: Conn_01x01_Pin; SolderWire-1.5sqmm_1x01_D1.7mm_OD3.9mm
J3: CW2B-10A-T; SolderWire-1.5sqmm_1x03_P7.8mm_D1.7mm_OD3.9mm
JP1: PFC_VCC_OK#; TestPoint_2Pads_Pitch2.54mm_Drill0.8mm
JP2: PFC Enable; SolderJumper-2_P1.3mm_Open_TrianglePad1.0x1.5mm
K1: SRD-12VDC-SL-C; Relay_SPDT_SANYOU_SRD_Series_Form_C
L1: BLM18EG221SN1D; L_0603_1608Metric
Q1: IRLML5203; SOT-23
QP1, QP2: STP13NK60Z; TO-220-3_Vertical
R1, R2, R3: JNR13S500L; RV_Disc_D12mm_W5.8mm_P7.5mm
R4: 150; R_0805_2012Metric
R5: 62K; R_0805_2012Metric
R6, R7: 1M; R_Axial_DIN0207_L6.3mm_D2.5mm_P7.62mm_Horizontal
R8: 220K; R_Axial_DIN0207_L6.3mm_D2.5mm_P7.62mm_Horizontal
R9: 33; R_0805_2012Metric
R10: 5; R_0805_2012Metric
R11, R16: 1K; R_0805_2012Metric
R12, R13: 2K; R_0805_2012Metric
R14: 39K; R_0805_2012Metric
R15: 3K; R_0805_2012Metric
R17: 10K; R_0805_2012Metric
R18: 100K; R_0805_2012Metric
R19: 1R; R_2512_6332Metric
RP1: 33K; R_0805_2012Metric
RP2, RP17: 0.12; R_2512_6332Metric
RP3: 10K; R_0805_2012Metric
RP4: 220; R_0805_2012Metric
RP5, RP6, RP7, RP13, RP14, RP15: 750K; R_0805_2012Metric
RP8: 75K; R_0805_2012Metric
RP9, RP10: 680K; R_0805_2012Metric
RP11: 620K; R_0805_2012Metric
RP12: 15K; R_0805_2012Metric
RP16: 68K; R_0805_2012Metric
RV1: FNR-14K431; R_Radial_Power_L16.1mm_W9.0mm_P7.37mm
TP1: HV GND; TestPoint_Plated_Hole_D1.0mm
TP3: Supply VCC; TestPoint_Pad_2.0x2.0mm
TP4: STB VCC; TestPoint_Pad_2.0x2.0mm
TR1: ETD 34/17/11@N87@s=3.3mm N27@1mm*2; ETD34_7x7_vertical
TR2: ETD 29/16/10@N87@s=0.2mm N41/8/9@0.5mm; ETD29_7x7_vertical
U1: ICE2PCS01; SO-8_3.9x4.9mm_P1.27mm
U2: TL331; SOT-23-5
U3: R7731; SOT-23-6
U4: EL817; DIP-4_W7.62mm
U5: TL432DBZ; SOT-23-3
Y1: B32022A3223M000; C_Rect_L18.0mm_W6.0mm_P15.00mm_FKS3_FKP3

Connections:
/Input power with filter/HV_GND: C2.2, C3.2, C4.1, C5.1, C7.1, C8.2, C9.1, C10.2, C11.1, CP1.2, CP2.2, CP3.2, CP4.2, CP5.2, J1.1, K1.2, QP1.3 (S), R5.1, R11.1, R15.1, R16.1, R18.1, R19.1, RP1.2, RP2.2, RP8.2, RP12.2, RP16.2, RP17.2, TP1.1, TR2.3, TR2.7, U1.1 (GND), U2.2 (V-), U3.1 (GND), U4.3, U5.3 (A)
/Input power with filter/OUT_400V: C3.1, C6.2, F1.2, J1.2, R6.2, R8.2, TR2.13
/Input power with filter/PFC_OK#: JP1.1 (A), U2.4
/Input power with filter/PFC_PRE_DIV: RP7.2, RP8.1, U2.3 (+)
/Input power with filter/PFC_VCC: CP4.1, JP2.2 (B), Q1.2 (S), R4.2, R17.2, U1.7 (VCC), U2.5 (V+)
/Input power with filter/PFC_VSENSE: RP11.2, RP12.1, U1.6 (VSENSE)
/Input power with filter/STARTUP_PROTECT_IN: J3.2, K1.1, R1.1, RV1.2
/Input power with filter/STARTUP_PROTECT_OUT: D1.3, K1.3, R3.2
/Input power with filter/VOUT_PRE_GND: C1.2, D1.4 (-), RP2.1, RP4.2, RP17.1, Y1.2
/Input power with filter/VOUT_PRE_PFC: C1.1, D1.1 (+), RP5.1, TR1.12, TR1.14
/Standby Supply/FEEDBACK: C7.2, U3.2 (COMP), U4.4
/Standby Supply/V_STANDBY: D5.2 (A), J2.1, Q1.3 (D), R18.2
unnamed: CP2.1, RP3.2
unnamed: D2.2 (A), QP2.2 (D), TR2.11
unnamed: C6.1, D2.1 (K), R8.1
unnamed: D3.2 (A), TR2.9
unnamed: C4.2, D3.1 (K), R7.1, TP3.1, U3.5 (VDD)
unnamed: D4.2 (A), TR2.5
unnamed: C8.1, D4.1 (K), L1.1, R12.2
unnamed: D5.1 (K), R11.2
unnamed: C10.1, D6.2 (A), JP2.1 (A), L1.2, R14.2, TP4.1
unnamed: D6.1 (K), R16.2
unnamed: DP1.2 (A), QP1.2 (D), TR1.2, TR1.4
unnamed: CP5.1, DP1.1 (K), F1.1, RP9.1, RP13.1
unnamed: D1.2, J3.1, RV1.1
unnamed: J3.3, Y1.1
unnamed: C11.2, JP1.2 (B), Q1.1 (G), R17.1
unnamed: K1.5, R4.1
unnamed: QP1.1 (G), U1.8 (GATE)
unnamed: QP2.1 (G), R9.1
unnamed: QP2.3 (S), R10.1, R19.2
unnamed: R1.2, R2.1
unnamed: R2.2, R3.1
unnamed: R6.1, R7.2
unnamed: R12.1, R13.2, U4.1
unnamed: RP5.2, RP6.1
unnamed: RP6.2, RP7.1
unnamed: RP9.2, RP10.1
unnamed: RP10.2, RP11.1
unnamed: RP13.2, RP14.1
unnamed: RP14.2, RP15.1
unnamed: RP1.1, U1.4 (FREQ)
unnamed: CP1.1, U1.2 (ICOMP)
unnamed: RP4.1, U1.3 (ISENSE)
unnamed: CP3.1, RP3.1, U1.5 (VCOMP)
unnamed: C2.1, RP15.2, RP16.1, U2.1 (-)
unnamed: C5.2, R10.2, U3.4 (CS)
unnamed: R9.2, U3.6 (GATE)
unnamed: R5.2, U3.3 (RT)
unnamed: R13.1, U4.2, U5.2 (K)
unnamed: C9.2, R14.1, R15.2, U5.1 (REF)

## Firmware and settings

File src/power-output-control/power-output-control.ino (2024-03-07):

#include "power_output_control.h"
#include "i2c_slave.h"
#include "config.h"
#include "uart_console.h"

void setup() {
  power_output_control_init();
  i2c_slave_init();

  #if UART_ENABLED
  uart_console_init();
  Serial.println("Ready!");
  #endif

  #if SET_DEFAULT_V_I_ON_START
  power_output_control_setI(100);
  power_output_control_setV(200);
  power_output_control_start(true);
  #endif
}

void loop() {
  power_output_control_on_main_loop();

  #if UART_ENABLED
  uart_console_on_main_loop();
  #endif
}

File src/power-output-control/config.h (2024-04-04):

#ifndef CONFIG_H_
#define CONFIG_H_

#define UART_ENABLED true
#define SET_DEFAULT_V_I_ON_START false

// C2
#define PIN_LED_OVERLOADED 12
// C3
#define PIN_LED_POWEROUTPUT 13

// A7
#define PIN_POWER_OUTPUT_SENSE_I PIN_PA7
// B4
#define PIN_POWER_OUTPUT_SENSE_V PIN_PB4

// A5
#define PIN_POWER_OUTPUT_IC_FB A5
// B5
#define PIN_POWER_OUTPUT_SHUTDOWN PIN_PB5

#define I2C_SLAVE_ADDRESS 0x33

#endif /* #define CONFIG_H_ */

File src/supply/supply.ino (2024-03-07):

#include "power_control.h"
#include "user_input.h"
#include "fan_control.h"
#include "gui_manager.h"
#include "display.h"
#include "pwm_control.h"

#include "Wire.h"

void setup() {
//  Serial.begin(9600);
//  delay(10);

  power_control_init();

  fan_control_init();
  pwm_control_init();
  user_input_init();
  display_init();
  gui_manager_init();
  pwm_control_configure_startup();

  user_input_start();

  Serial.println("Chip ready");
}

void loop() {
  fan_control_on_main_loop();
  gui_manager_on_main_loop();
  power_control_on_main_loop();

  delay(10); // ~100Hz refresh screen rate, I think it's OK )
}

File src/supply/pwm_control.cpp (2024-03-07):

#include "pwm_control.h"

#include "Arduino.h"
#include "SPI.h"
#include "config.h"
#include "Wire.h"

#define PWM_CONTROL_DAC_I2C_ADDRESS    0x60

#define PWM_CONTROL_PIN_SIGNAL_CS      9 // PB1
#define PWM_CONTROL_PIN_GEN_SHUTDOWN   0 // PD0
#define PWM_CONTROL_PIN_GEN_ALWAYS_ON  A1

#define PWM_CONTROL_DEFAULT_FREQ 40000
#define PWM_CONTROL_DEFAULT_DUTY 20

#define PWM_CONTROL_GENOUT_MINV  50
#define PWM_CONTROL_GENOUT_VPP   450
#define PWM_CONTROL_GENOUT_MAXV  (PWM_CONTROL_GENOUT_MINV + PWM_CONTROL_GENOUT_VPP)

#define PWM_CONTROL_MIN_FREQ 1
#define PWM_CONTROL_MAX_FREQ 1000000

SPISettings spisettings = SPISettings(SPI_DEFAULT_FREQ, MSBFIRST, SPI_MODE2);

uint32_t pwm_control_freq = PWM_CONTROL_DEFAULT_FREQ;
uint8_t pwm_control_duty = PWM_CONTROL_DEFAULT_DUTY;
bool pwm_control_enabled = false;

void pwm_contorl_reset_dac();
void pwm_contorl_reset_gen();
void pwm_control_reconfigure_dac();
void pwm_control_reconfigure_gen();
void pwm_control_apply();
void pwm_control_spi_write16(uint16_t value);
void pwm_control_spi_write32(uint16_t value1, uint16_t value2);
void pwm_control_ic2_write24(uint8_t value1, uint8_t value2, uint8_t value3);

void pwm_control_init() {
  pinMode(PWM_CONTROL_PIN_GEN_SHUTDOWN, OUTPUT);
  digitalWrite(PWM_CONTROL_PIN_GEN_SHUTDOWN, HIGH);

  pinMode(PWM_CONTROL_PIN_GEN_ALWAYS_ON, OUTPUT);
  digitalWrite(PWM_CONTROL_PIN_GEN_ALWAYS_ON, LOW);

  pinMode(PWM_CONTROL_PIN_SIGNAL_CS, OUTPUT);
  digitalWrite(PWM_CONTROL_PIN_SIGNAL_CS, HIGH);
}

void pwm_control_configure_startup() {
  pwm_control_apply();
}

void pwm_control_set(uint32_t freq, uint8_t duty) {
  if (freq <= PWM_CONTROL_MAX_FREQ && freq >= PWM_CONTROL_MIN_FREQ && duty <= 100) {
    pwm_control_freq = freq;
    pwm_control_duty = duty;

    if (pwm_control_enabled) {
      pwm_control_apply();
    }
  }
}

void pwm_control_add_freq(uint16_t delta, bool add) {
  if (add) {
    if (pwm_control_freq + delta < PWM_CONTROL_MAX_FREQ) {
      pwm_control_freq += delta;
    } else {
      pwm_control_freq = PWM_CONTROL_MAX_FREQ;
    }
  } else {
    if (pwm_control_freq > delta + PWM_CONTROL_MIN_FREQ) {
      pwm_control_freq -= delta;
    } else {
      pwm_control_freq = PWM_CONTROL_MIN_FREQ;
    }
  }

  if (pwm_control_enabled) {
    pwm_control_apply();
  }
}

void pwm_control_add_duty(uint8_t delta, bool add) {
  if (add) {
    if (pwm_control_duty + delta < 100) {
      pwm_control_duty += delta;
    } else {
      pwm_control_duty = 100;
    }
  } else {
    if (pwm_control_duty > delta) {
      pwm_control_duty -= delta;
    } else {
      pwm_control_duty = 0;
    }
  }

  if (pwm_control_enabled) {
    pwm_control_apply();
  }
}

void pwm_control_start() {
  pwm_control_start(!pwm_control_enabled);
}

void pwm_control_start(bool enabled) {
  if (pwm_control_enabled != enabled) {
    pwm_control_enabled = enabled;
    pwm_control_apply();
  }
}

void pwm_control_apply() {
  Serial.print("pwm_control_apply: ");
  Serial.print(pwm_control_freq);
  Serial.print("Hz; ");
  Serial.print(pwm_control_duty);
  Serial.print("%; ");
  Serial.println(pwm_control_enabled ? "enabled" : "disabled");
 if (pwm_control_enabled) {
    digitalWrite(PWM_CONTROL_PIN_GEN_SHUTDOWN, HIGH);

    if (pwm_control_duty == 100 || pwm_control_duty == 0) {
      pwm_contorl_reset_dac();
      pwm_contorl_reset_gen();
    } else {
      pwm_control_reconfigure_dac();
      pwm_control_reconfigure_gen();
    }

    digitalWrite(PWM_CONTROL_PIN_GEN_ALWAYS_ON, (pwm_control_duty == 100) ? HIGH : LOW);
    
    digitalWrite(PWM_CONTROL_PIN_GEN_SHUTDOWN, LOW);
  } else {
    digitalWrite(PWM_CONTROL_PIN_GEN_SHUTDOWN, HIGH);
    digitalWrite(PWM_CONTROL_PIN_GEN_ALWAYS_ON, LOW);

    pwm_contorl_reset_dac();
    pwm_contorl_reset_gen();
  }
}

void pwm_control_status(t_pwm_control_status & status) {
  status.duty = pwm_control_duty;
  status.freq = pwm_control_freq;
  status.enabled = pwm_control_enabled;
}

void pwm_contorl_reset_dac() {
  pwm_control_ic2_write24(_BV(6) | _BV(4) | _BV(3) | _BV(1), 0, 0);
}

void pwm_contorl_reset_gen() {
  pwm_control_spi_write16(_BV(8) | _BV(6) | _BV(7));
}

void pwm_control_reconfigure_dac() {
  uint16_t vout = PWM_CONTROL_GENOUT_MAXV - ((uint32_t)PWM_CONTROL_GENOUT_VPP * (uint32_t)pwm_control_duty / (uint32_t)100);
  uint16_t dacreg = ((uint32_t)vout * (uint32_t)4095) / (uint32_t)4096;

  Serial.print("dac vout = ");
  Serial.println(vout);

  pwm_control_ic2_write24(_BV(6) | _BV(4) | _BV(3), (dacreg >> 4), ((dacreg & 0b00001111) << 4));
}

void pwm_control_reconfigure_gen() {
  pwm_control_spi_write16(_BV(13) | _BV(8));

  uint32_t freqreg = (((uint64_t)pwm_control_freq) * ((uint64_t)268435456)) / (uint64_t)25000000;
  Serial.print("freqreg = ");
  Serial.println(freqreg);

  uint16_t freq0 = _BV(14) + (freqreg & 0b0011111111111111);
  uint16_t freq1 = _BV(14) + (freqreg >> 14);

  pwm_control_spi_write32(freq0, freq1);

  pwm_control_spi_write16(_BV(15) | _BV(14));

  pwm_control_spi_write16(_BV(13) | _BV(1));
}

void pwm_control_spi_write16(uint16_t value) {
  SPI.beginTransaction(spisettings);
  digitalWrite(PWM_CONTROL_PIN_SIGNAL_CS, LOW);

  SPI.transfer16(value);

  digitalWrite(PWM_CONTROL_PIN_SIGNAL_CS, HIGH);
  SPI.endTransaction();

  Serial.print("SPI write ");
  Serial.println(value, HEX);
}

void pwm_control_spi_write32(uint16_t value1, uint16_t value2) {
  SPI.beginTransaction(spisettings);
  digitalWrite(PWM_CONTROL_PIN_SIGNAL_CS, LOW);

  SPI.transfer16(value1);
  SPI.transfer16(value2);

  digitalWrite(PWM_CONTROL_PIN_SIGNAL_CS, HIGH);
  SPI.endTransaction();

  Serial.print("SPI write ");
  Serial.print(value1, HEX);
  Serial.print(" / ");
  Serial.println(value2, HEX);
}

void pwm_control_ic2_write24(uint8_t value1, uint8_t value2, uint8_t value3) {
  Wire.beginTransmission(PWM_CONTROL_DAC_I2C_ADDRESS);
  Wire.write(value1);
  Wire.write(value2);
  Wire.write(value3);
  Wire.endTransmission(true);

  Serial.print("I2C write: ");
  Serial.print(value1, HEX);
  Serial.print(" / ");
  Serial.print(value2, HEX);
  Serial.print(" / ");
  Serial.println(value3, HEX);
}

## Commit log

2023-06-29 created boards
    [calc.ods, control.kicad_sch, input_filter.kicad_sch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]
2023-07-07 prepare to replace ina228 to attiny16+ina169(?). ina228 is an intresting chip, but its too expensive and Im not sure I can buy it on ali
    [calc.ods, control.kicad_sch, input_filter.kicad_sch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]
2023-07-11 Prepare to move USB ports to a few millimenters outside
    [calc.ods, control.kicad_sch, output_5v_usb.kicad_sch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]
2023-07-11 Updated boards
    [calc.ods, output_5v_usb.kicad_sch, standby_supply.kicad_sch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]
2023-07-12 little changes in schematics
    [calc.ods, control.kicad_sch, input_filter.kicad_sch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]
2023-07-12 prepare to add current measurement for a middle-current 5V and 3.3V lines
    [control.kicad_sch, output_5v_usb.kicad_sch, output_connectors.kicad_sch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]
2023-07-13 prepare to replace inductor on 5V power line
    [calc.ods, output_5v_usb.kicad_sch, output_connectors.kicad_sch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]
2023-07-13 Added over-voltage protection to 5V line
    [control.kicad_sch, output_5v_usb.kicad_sch, output_connectors.kicad_sch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]
2023-07-17 Fixed problem with 20V on one leg of comparator
    [control.kicad_sch, input_filter.kicad_sch, output_5v_usb.kicad_sch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]
2023-07-17 Some changes in board - Im preparing it to production
    [control.kicad_sch, input_filter.kicad_sch, output_5v_usb.kicad_sch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]
2023-07-17 Changed fuse on 400V line
    [input_filter.kicad_sch, output_connectors.kicad_sch, supply.csv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]
2023-07-19 Board prepared to order
    [calc.ods, input_filter.kicad_sch, output_5v_usb.kicad_sch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]
2023-07-19 Created gerber-files to check order cost
    [supply-B_Cu.gbr, supply-B_Mask.gbr, supply-B_Paste.gbr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]
2023-07-24 One board settings changed from 4-layers to 2-layers to reduce it's price
    [control.kicad_sch, output_5v_usb.kicad_sch, output_connectors.kicad_sch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]
2023-07-24 Project splited to 2 sub-projects - I want to reduce board production price
    [input_filter.kicad_sch, output_5v_usb.kicad_sch, power_output.kicad_sch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]
2023-07-24 UV board size changed to 100x100 to reduce production price
    [control.kicad_sch, output_5v_usb.kicad_sch, output_connectors.kicad_sch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]
2023-07-25 Added Li-Ion charger port
    [output_connectors.kicad_sch, supply.kicad_pcb]
2023-08-07 Boards prepared to order
    [input_filter.kicad_sch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]
2023-09-18 First firmware (not tested)
    [output_5v_usb.kicad_sch, power_output.kicad_sch]
2023-09-20 main firmware - ready to write UI
    [control.kicad_sch, output_5v_usb.kicad_sch, output_connectors.kicad_sch]
2023-10-18 Found and fixed issues in schematics.
    [calc.ods, control.kicad_sch, input_filter.kicad_sch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]
2023-10-19 standby & pfc almost works
    [calc.ods, standby_supply.kicad_sch]
2023-10-21 Some changes
    [calc.ods, control.kicad_sch, output_5v_usb.kicad_sch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]
2023-10-23 Preapare firmwware to upload on device
    [box-matrix-front.stl, box-matrix-usb.stl, box.FCStd]
2023-10-24 fix pins in firmware
    [control.kicad_sch, output_5v_usb.kicad_sch, output_connectors.kicad_sch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]
2023-10-31 Continue soldering and setting up hardware
    [box-fuse-holder-cup.stl, box-fuse-holder.stl, box.FCStd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]
2023-10-31 supply-uv, new board ordered
    [supply-uv-B_Cu.gbr, supply-uv-B_Mask.gbr, supply-uv-B_Paste.gbr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]
2023-11-05 Board fixes
    [calc.ods, output_5v_usb.kicad_sch, supply.kicad_pcb]
2023-11-05 Fix reading current from INA3221
    [display.cpp, power_control.cpp, supply.ino]
2023-11-16 supply board - power controllers changed; PWM logic changed
    [box-fuse-holder.stl, box.FCStd, calc.ods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]
2023-11-18 re-design supply board
    [calc.ods, control.kicad_sch, output_5v_usb.kicad_sch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]
2023-12-28 Fixed error on board, v1.3 ordered
    [control.kicad_sch, output_connectors.kicad_sch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]
2024-03-07 Continue project
    [calc.ods, control.kicad_sch, output_5v_usb.kicad_sch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]
2024-04-04 some changes in schema. I found additional error. This commit saves changes before re-write some blocks
    [box-matrix-front.stl, box.FCStd, calc.ods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]
2024-06-24 debugging DCDC converters... Standby supply works fine (noise level = 1,7%). At now Starting to debug PFC module
    [calc.ods, control.kicad_sch, input_filter.kicad_sch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]
2024-06-28 I cant fix problem with 2MHZ@3V noise under 5V section. It came from POWER GND line (common for standby supply & 400V line). So, I make desision to rewrite schema
    [calc.ods]
